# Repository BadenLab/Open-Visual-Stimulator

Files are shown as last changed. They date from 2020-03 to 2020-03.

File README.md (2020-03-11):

<p align="right">
<h1 align="center">Open Visual Stimulator</h1></p>
<h3 align="center">An open source arbitrary-spectrum spatial visual stimulator for vision research.</h4>
<p align="center"><h6 align="right">by K. Franke, A.M. Chagas, Z. Zhao, M.J.Y. Zimmermann, Y. Qiu, K. Szatko, T. Baden, T. Euler</h6></p>

<br>

### This project is a part of a larger work that can be found on the [Euler lab GitHub](https://github.com/eulerlab/open-visual-stimulator)

This project is licensed under the [MIT License](https://github.com/BadenLab/open-visual-stimulator/blob/master/LICENSE)<br>

<h4 align="justify">This repository holds the resources for a flexible, spatial visual stimulator with up to 6 chromatic channels. It combines commercial digital light processing (DLP) devices with open hard- and software components that can be easily adapted to the experimentalist’s specific needs. With this we intend to start a community effort of sharing and further developing a common stimulator design.</h4></p>

Please find more details on the stimulator in the following publication:

_Franke K*, Maia Chagas A*, Zhao Z, Zimmermann MJY, Bartel P, Qiu Y, Szatko K, Baden T, Euler T# (2019). An arbitrary-spectrum spatial visual stimulator for vision research. eLife 2019;8:e48779, [10.7554/eLife.48779](https://elifesciences.org/articles/48779)._

For the newest changes and additions, see [release notes](https://github.com/eulerlab/open-visual-stimulator/blob/master/release_notes.md)

### Pictures

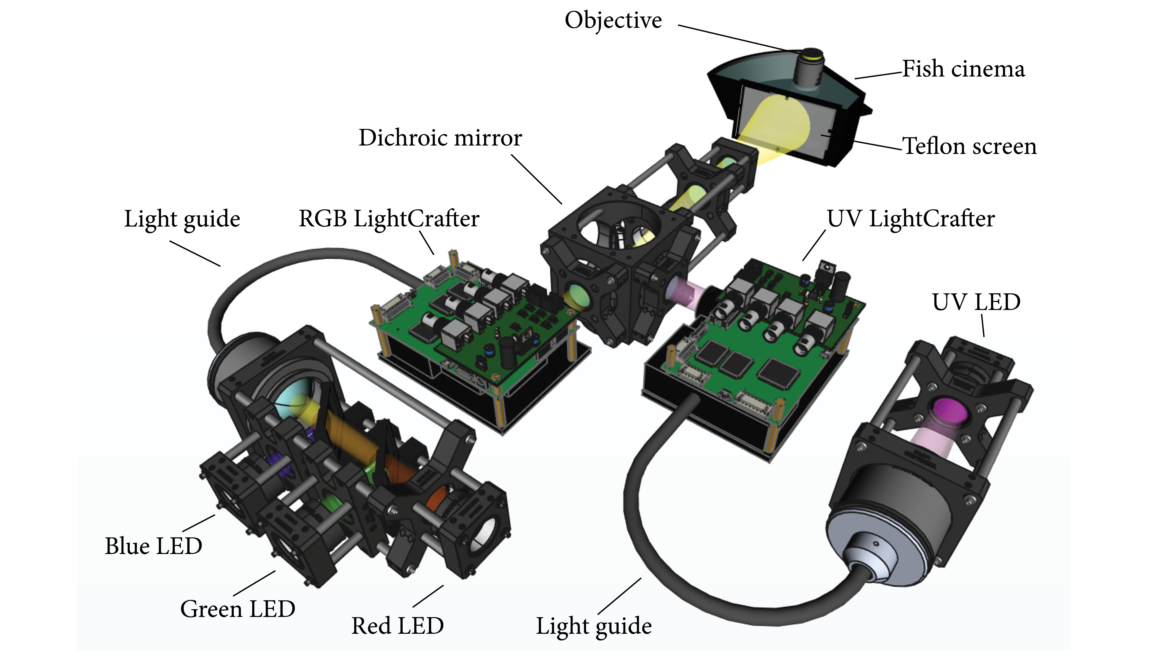
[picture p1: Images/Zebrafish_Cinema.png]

_Rendering of the 4-channel R-G-B-UV zebrafish stimulator._

### Ordering of PCB boards

If you are interested in ordering boards and components, please find more information in the boards folder [readme](https://github.com/badenlab/open-visual-stimulator/blob/master/PCB/readme.md) file.

## Repository structure

```
├───3D Designs                                OpenSCAD and STL files for 3D printed parts
|   |
│   ├───Fish_cinema                           - Fish tank used in the fish setup
│   ├───SSR_board                             - Designs for plate and cover of the SSR board
│   └───optical_components                    - optomechanical parts for LED assemblies
|           ├───fish_stimulator
|           └───lcr_addons
|
├───Images                                    Pictures
|
├───PCB                                       LED driver/blanking boards
│   ├───lcr_add-on                            - KiCad files for board that combines LCr and
|   |   |                                       blanking signals
|   |   ├───connector_coaxial.pretty          - BNC connector description (KiCad)
|   |   └───gerber                            - Gerber files for circuit board
│   ├───mosfet_circuit                        - KiCad files for board that switches switch LEDs
|   |   ├───connector_coaxial.pretty          - BNC connector description (KiCad)
|   |   └───gerber                            - Gerber files for circuit board
|   ├───mosfet_circuit_plus_voltage_regulator - KiCad files for board that combines voltage
|   |   |                                       regulator and LED switching
|   |   ├───connector_coaxial.pretty          - BNC connector description (KiCad)
|   |   └───gerbers                           - Gerber files for circuit board
|   ├───ssr_board                             - KiCad files for solid state relay board
|   |   └───gerbers                           - Gerber files for circuit board
|   └───arduino_code_for_testing_circuits     - Arduino code to emulate blanking and LCr signals
|       └───lcr_emulator
|
└───Stimulator Calibration                    Calibration of tetrachromatic zebrafish stimulator
    ├───data                                  - recorded calibration data (custom LEDs)
    ├───datasheets                            - spectrometer & powermeter data sheet.
    ├───light-sources                         - LED spectra measured behind the teflon screen
    ├───opsins                                - zebrafish opsin sensitivity curves
    └───scripts                               - Python scripts used in iPython notebooks
```

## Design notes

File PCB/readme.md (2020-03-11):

## LED driver/blanking boards

LED blanking circuits were inspired by earlier devices designed and built by R. Berndt (HIH Tübingen).

`lcr_add-on` - KiCad and Gerber files for the "logic board". This board combines the signals from the LCr with an external "blanking signal" to independently control up to three 3 LEDs per lightcrafter device. This board has a jumper option to disable the blanking signal altogether, which may be useful when e.g. using LCrs in MEA setups.

`mosfet_circuit` - KiCad and Gerber files for "LED driver board". This board uses the 5V logic signal from Lcr_addon ("logic board") to turn LEDs on and off. Users need to connect this board to an appropriate power suply (i.e. a power supply the is outputing the LED forward voltage).

`mosfet_circuit_plus_voltage_regulator` - KiCad and Gerber files for "LED driver board". This board uses the 5V logic signal from Lcr_addon ("logic board") to turn LEDs on and off. This board has a stepdown voltage regulator built-in. It is capable of 20V and 1.5A max output with the components present in its "1-click-bom.csv" file. (see "Components to populate the boards" for more details).

`ssr_board` - This board controls the LED power lines from the Lightcrafter by opening and closing them using solid state relays. The relays are controlled by a 5V signal (in this case the inverted blanking signal).

### General information about the printed circuit boards:

- For details on the design and function of the boards, see [preprint](https://www.biorxiv.org/content/10.1101/649566v1)).

- The boards were designed using [KiCad 5](http://www.kicad-pcb.org/) and can be ordered using the `Gerber.zip` file located in each board's `gerber` subfolder.

- Several "board on demand" companies are available, and the process of ordering is pretty much the same. A more detailed tutorial on how to do so can be found [here](https://www.youtube.com/watch?v=ENmDnoKs2hM) (for simply using the already available compressed files, go to minute 7 of the video).

- Companies providing "board on demand" service include:

   - [JLCPCB](https://jlcpcb.com/)
   - [PCBWAY](https://www.pcbway.com)
   - [OSH PARK](https://oshpark.com/)
   - [AISLER](https://aisler.net/)

### Components to populate the boards:

Components are listed on each board folder on a "comma separated value" file named `1-click-bom.csv`. Listed in the file are the quantity, identification and supplier of each component. They can also be ordered using [KitSpace](kitspace.org):

 - [LCr_addon on kitspace](https://kitspace.org/boards/github.com/eulerlab/open-visual-stimulator/boards/lcr_add-on/)
 - [mosfet circuit on kitspace](https://kitspace.org/boards/github.com/eulerlab/open-visual-stimulator/boards/mosfet_circuit/)

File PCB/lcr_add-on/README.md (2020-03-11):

# Open Visual Stimulator - LCR add-on PCB

A board for integrating signals from a lightcrafter to a 2P microscope ("logic board"), part of the Open source visual stimulator project.

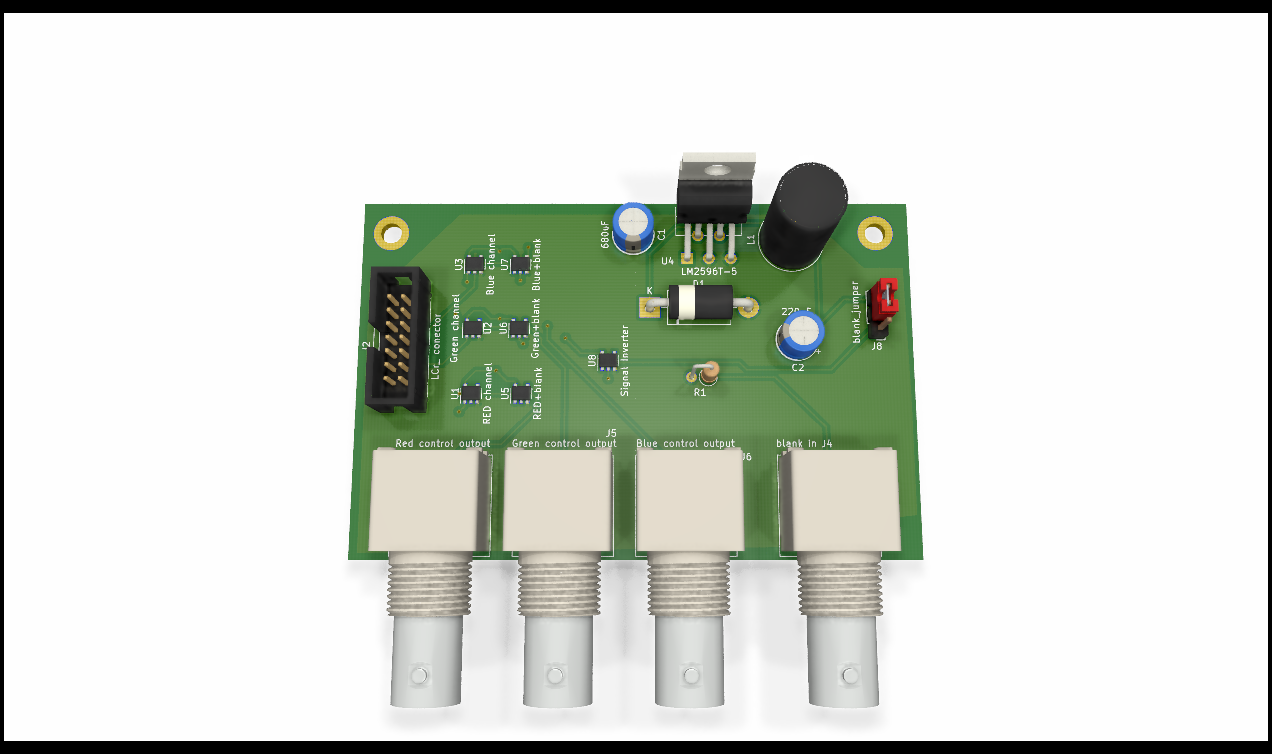
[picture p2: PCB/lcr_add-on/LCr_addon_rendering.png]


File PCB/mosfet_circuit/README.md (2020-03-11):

# Open Visual Stimulator - MOSFET Circuit PCB

A board ("LED driver board") for fast switching LEDs on/off, part of the Open Source visual stimulator project.

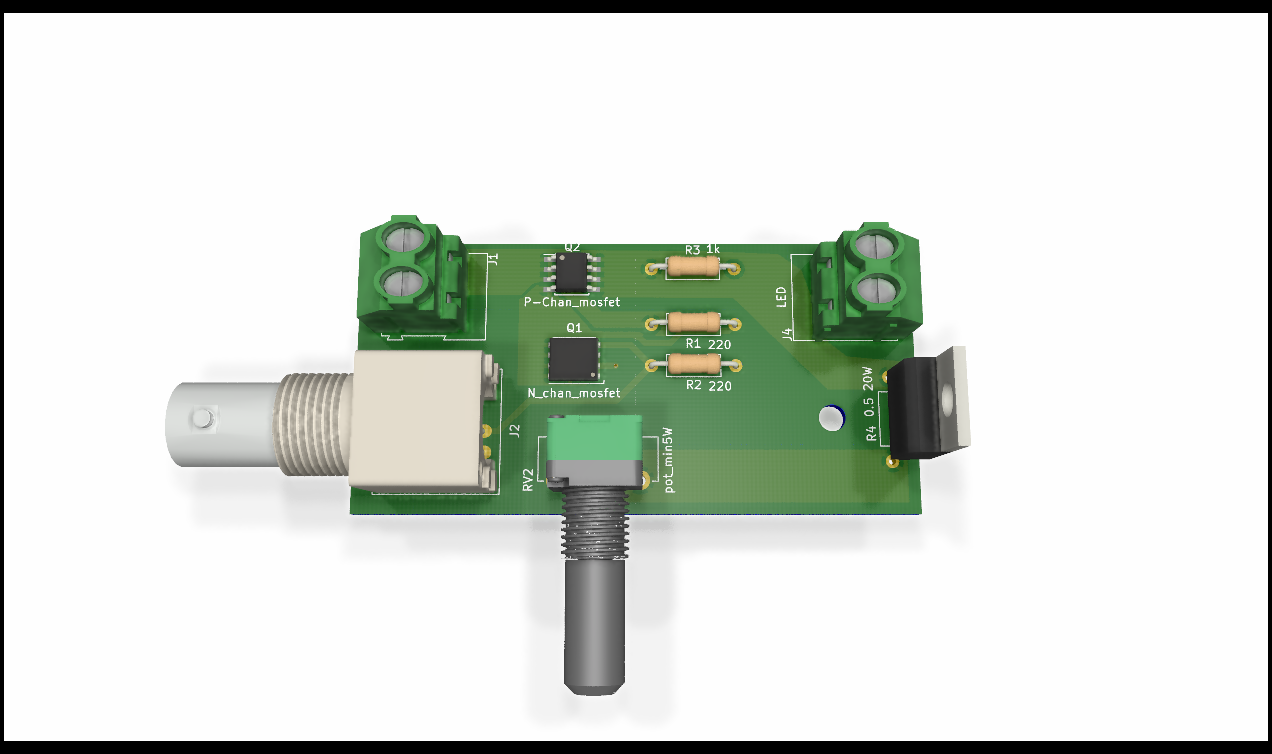
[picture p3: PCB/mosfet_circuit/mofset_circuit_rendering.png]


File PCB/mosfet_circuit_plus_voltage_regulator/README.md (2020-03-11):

# Open Visual Stimulator - mosfet circuit plus voltage regulator

A board that contains a voltage regulator and a fast switching (tens of microsseconds) circuit for turning LEDs on and off

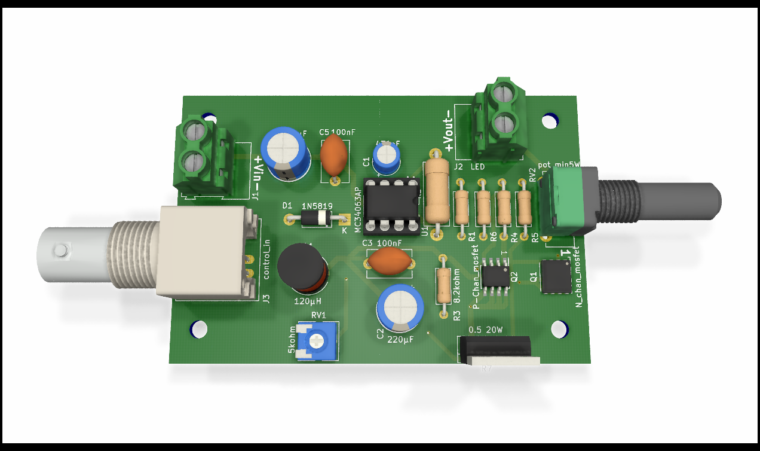
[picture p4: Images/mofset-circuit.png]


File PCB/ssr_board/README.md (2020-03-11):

# Open Visual Stimulator - Solid State relay board

This board controls the LED power lines from the Lightcrafter by opening and closing them using solid state relays. The relays are controlled by a 5V signal (in this case the inverted blanking signal).

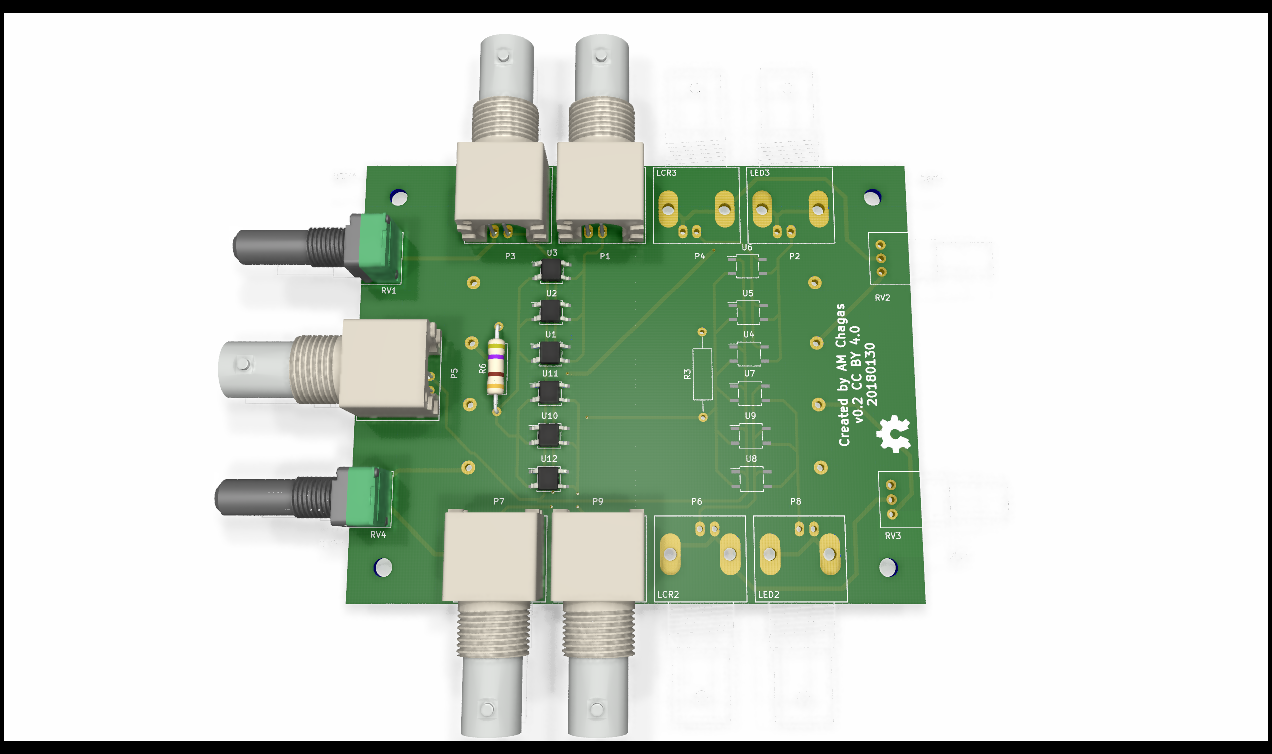
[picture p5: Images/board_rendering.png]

rendering for two out of four possible channels.

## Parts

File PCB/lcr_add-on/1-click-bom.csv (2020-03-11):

References | Qty | Description | Manufacturer | MPN | Manufacturer_1 | MPN_2 | Manufacturer_3 | MPN_4 | Manufacturer_5 | MPN_6 | Manufacturer_7 | MPN_8 | Digikey | Mouser | RS | Newark | Farnell
U4; | 1 | LM2596 5v | ITO-220 | Texas Instruments | Texas Instruments | LM2596T-5.0/NOPB |  |  |  |  |  |  | LM2596T-5.0/NOPB-ND | 926LM2596T5.0/NOPB | 5333743 | 97K3256 | 1150103
L1; | 1 | INDUCTOR 33µH Neosid MA-Bs75 | Bourns | RLB0914-330KL |  |  |  |  |  |  |  |  | RLB0914-330KL-ND | 652RLB0914330KL | 8118853 | 61J7916 | 2309242
D1; | 1 | Diode Schottky 5A DO-201AD | Vishay | 1N5822-E3/73 | Zetex | SB5100-T |  |  |  |  |  |  | 1N5822-E3/73GICT-ND | 6251N5822E3/73 | 751-4843 | 17T8202 | 1336553
C2; | 1 | CAP ALUM 220UF 20% 25V RADIAL | Panasonic | EEU-FM1E221 | Panasonic | ECA-1CM221B | Panasonic | ECE-A0GKS221 | Panasonic | EEU-EB1A221S |  |  | P12383-ND | 667ECA1CM221B | 7472036 | 70K9673 | 9451099
C1; | 1 | 680µF Capacitor | Rubycon | 16ZL680MEFC10X16 | Panasonic | EEU-FC1A681 |  |  |  |  |  |  | 1189-3978-ND | 667EEUFC1A681 | 7037258 | 31M6417 | 1144691
R1; | 1 | Resistor 1k 250mW through-hole | Multicomp | MF12 1K | Yageo | MFR-25FBF52-1K | RS Pro | 7077666 |  |  |  |  | 1.00KXBK-ND | 603MFR25FBF521K | 7077666 | 38K5400 | 9342400
J2; | 1 | Lcr connector | JST | B14B-PHDSS (LF)(SN) |  |  |  |  |  |  |  |  | 455-1764-ND |  | 918-2738
J4;J5;J6;J7; | 4 | BNC connector | TE | 1-1337542-0 |  |  |  |  |  |  |  |  | A97552-ND |  | 512-1203
J8; | 1 | jumper connector | SamTec | SSW-103-01-G-S |  |  |  |  |  |  |  |  | SAM1209-03-ND |  | 765-5610
U1;U2;U3:U5;U6:U7 | 6 | AND gate | NXP | '74AHC1G08GW | 125' |  |  |  |  |  |  |  |  | 1727-3148-1-ND | 144-5258 | 510-087
U8; | 1 | Signal inverter (NOT gate) | Toshiba | TC7SH14F(F) | Texas Instruments | 74AHC1G14SE-7 |  |  |  |  |  |  | 74AHC1G14SE-7DICT-ND |  | 540-6885
Lcr 1 | 2 | Female plug 2X14 (1 to Lcr one to Board) | JST | PHDR-14VS |  |  |  |  |  |  |  |  | 455-1172-ND |  | 917-4692 | 917-4692
Cable | 14 | JUMPER SPHD-001T-P0.5 X2 10 | JST | APAPA22K254 |  |  |  |  |  |  |  |  | 455-3357-ND

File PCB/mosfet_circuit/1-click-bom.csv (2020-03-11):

References | Qty | Description | Manufacturer | MPN | Manufacturer_1 | MPN_2 | Manufacturer_3 | MPN_4 | Manufacturer_5 | MPN_6 | Manufacturer_7 | MPN_8 | Digikey | Mouser | RS | Newark | Farnell
Q2 | 1 | P-Channel MOSFET | Fairchild | FDS6575 |  |  |  |  |  |  |  |  | FDS6575CT-ND |  | 671-0570
Q1 | 1 | N-Channel mosfet | Vishay | SI4840BDY-T1-GE3 |  |  |  |  |  |  |  |  | SI4840BDY-T1-E3CT-ND |  | 710-4736
'R1;R2''' | 2 | Resistor 220 ohm 250mW through-hole | Yageo | MFR-25FBF52-220R | TE Connectivity | CBT25J220R | TE Connectivity | CFR16J220R | Ohmite | OD221JE | Stackpole Electronics | CF14JT220R | CF14JT220RCT-ND | 279CBT25J220R | 8066376 | 21R0186 | 1265068
R3 | 1 | Resistor 1k 250mW through-hole | Multicomp | MF12 1K | Yageo | MFR-25FBF52-1K | RS Pro | 7077666 |  |  |  |  | 1.00KXBK-ND | 603MFR25FBF521K | 7077666 | 38K5400 | 9342400
R4; | 1 | Resistor 20W TO-220 | Bourns | PWR220T-20-R500F |  |  |  |  |  |  |  |  | PWR220T-20-R500F-ND | 652PWR220T20R500F | 7962508 | 55R1098 | 2328267
J1;J4 | 2 | Terminal block 5mm | RS Pro | 494-8906 | TE Connectivity | 282837-2 |  |  |  |  |  |  | A113320-ND |  | 494-8906
RV2 | 1 | Potentiometer 25Ohms 5W | CTS | 026TB32R250B1A1 |  |  |  |  |  |  |  |  | CT2152-ND |  | 179-0668
J2 | 1 | BNC connector | TE | 1-1337542-0 |  |  |  |  |  |  |  |  | A97552-ND |  | 512-1203

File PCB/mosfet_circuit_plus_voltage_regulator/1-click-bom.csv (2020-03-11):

References | Qty | Description | Manufacturer | MPN | Manufacturer_1 | MPN_2 | Manufacturer_3 | MPN_4 | Manufacturer_5 | MPN_6 | Manufacturer_7 | MPN_8 | Digikey | Mouser | RS | Newark | Farnell
Q2 | 1 | P-Channel MOSFET | Fairchild | FDS6575 |  |  |  |  |  |  |  |  | FDS6575CT-ND |  | 671-0570
Q1 | 1 | N-Channel mosfet | Vishay | SI4840BDY-T1-GE3 |  |  |  |  |  |  |  |  | SI4840BDY-T1-E3CT-ND |  | 710-4736
R1 | 1 | 1.5kohm | TE Connectivity | LR1F1K5 |  |  |  |  |  |  |  |  | A105952CT-ND |  | 148-540
R2 | 1 | 0.22ohm | Vishay | RWM0410R220JR15E1 |  |  |  |  |  |  |  |  | RWMA-.22CT-ND |  | 485-1414
R3 | 1 | 8.2kohm | TE Connectivity | LR1F8K2 | Vishay | MRS25000C8201FCT00 |  |  |  |  |  |  | BC4264CT-ND |  | 148-714
R4;R5 | 2 | Resistor 220 ohm 250mW through-hole | Yageo | MFR-25FBF52-220R | TE Connectivity | CBT25J220R | TE Connectivity | CFR16J220R | Ohmite | OD221JE | Stackpole Electronics | CF14JT220R | CF14JT220RCT-ND | 279CBT25J220R | 8066376 | 21R0186 | 1265068
R6 | 1 | Resistor 1k 250mW through-hole | Multicomp | MF12 1K | Yageo | MFR-25FBF52-1K | RS Pro | 7077666 |  |  |  |  | 1.00KXBK-ND | 603MFR25FBF521K | 7077666 | 38K5400 | 9342400
R7 | 1 | Resistor 20W TO-220 | Bourns | PWR220T-20-R500F |  |  |  |  |  |  |  |  | PWR220T-20-R500F-ND | 652PWR220T20R500F | 7962508 | 55R1098 | 2328267
J1;J2 | 2 | Terminal block 5mm | RS Pro | 494-8956 | TE Connectivity | 282836-2 | TE Connectivity | 282837-2 |  |  |  |  | A113320-ND |  | 494-8956
J3 | 1 | BNC connector | TE | 1-1337542-0 |  |  |  |  |  |  |  |  | A97552-ND |  | 512-1203
RV1 | 1 | 5kohm | Bourns | 3362P-1-502LF |  |  |  |  |  |  |  |  | 3362P-502LF-ND |  | 522-0978
RV2 | 1 | Potentiometer 25Ohms 5W | CTS | 026TB32R250B1A1 |  |  |  |  |  |  |  |  | CT2152-ND |  | 179-0668
D1 | 1 | 1N5819 diode | ON | 1N5819G |  |  |  |  |  |  |  |  | 1N5819GOS-ND |  | 774-3347
C1 |  | 470pF capacitor | Vishay | 562R10TST47 |  |  |  |  |  |  |  |  | 562R10TST47-ND |  | 831-3023
C2;C4 |  | 220µF capacitor (line filter) | Vishay | MAL214650221E3 |  |  |  |  |  |  |  |  | 4485PHBK-ND |  | 684-1725
C3;C5 |  | 100nF capacitor (line filter) | Wima | MKS2D031001A00KI00 | TDK | FG26C0G1H104JNT06 |  |  |  |  |  |  | 445-173396-1-ND |  | 108-2700
L1 |  | 120µH inductor | Panasonic | ELC11D121F | Bourns | RL622-121K-RC |  |  |  |  |  |  | M9994-ND |  | 675-5400
U1 |  | MC34063AP step up/down regulator | texas instruments | MC34063AP |  |  |  |  |  |  |  |  | 296-17766-5-ND |  | 661-8430
U1-1 |  | DIP-8 socket | Preci-dip | 110-87-308-41-001101 | Assmann | A 08-LC-TT |  |  |  |  |  |  | AE9986-ND |  | 674-2435

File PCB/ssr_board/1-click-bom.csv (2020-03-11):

References | Qty | Description | Manufacturer | MPN | Manufacturer_1 | MPN_2 | Manufacturer_3 | MPN_4 | Manufacturer_5 | MPN_6 | Manufacturer_7 | MPN_8 | Digikey | Mouser | RS | Newark | Farnell
P1-9 | 9 | BNC connector | TE | 1-1337542-0 |  |  |  |  |  |  |  |  |  |  | 512-1203
R3;R6 | 2 | Resistor 1k 250mW through-hole | Multicomp | MF12 1K | Yageo | MFR-25FBF52-1K | RS Pro | 7077666 |  |  |  |  | 1.00KXBK-ND | 603MFR25FBF521K | 7077666 | 38K5400 | 9342400
RV1-4 | 4 | Potentiometer 25Ohms 5W | CTS | 026TB32R250B1A1 |  |  |  |  |  |  |  |  |  |  | 179-0668
U1-12 | 12 | Optocoupler 250mA max current | Panasonic | AQY221R2S |  |  |  |  |  |  |  |  |  |  | 699-6610
R1;R2;R4;R5 | 4 | 2 Ohm 5W resistor | Vishay | RS0052R000FE12 |  |  |  |  |  |  |  |  |  |  | 850-6613

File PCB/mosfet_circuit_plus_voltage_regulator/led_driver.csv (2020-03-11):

Source: | /home/andre/Documents/repositories/amchagas/open-visual-stimulator/boards/mosfet_circuit_plus_voltage_regulator/led_driver.sch
Date: | Fri 19 Jul 2019 14:24:53 BST
Tool: | Eeschema 5.0.2-bee76a0~70~ubuntu18.04.1
Component Count: | 26
Ref | Value | Footprint | Datasheet | Manufacturer | Vendor
C1 | 470pF | Capacitor_THT:CP_Radial_D5.0mm_P2.50mm | ~
C2 | 220µF | Capacitor_THT:CP_Radial_D8.0mm_P5.00mm | ~
C3 | 100nF | Capacitor_THT:C_Disc_D8.0mm_W5.0mm_P7.50mm | ~
C4 | 220µF | Capacitor_THT:CP_Radial_D8.0mm_P5.00mm | ~
C5 | 100nF | Capacitor_THT:C_Disc_D8.0mm_W5.0mm_P7.50mm | ~
D1 | 1N5819 | Diode_THT:D_DO-41_SOD81_P10.16mm_Horizontal | http://www.vishay.com/docs/88525/1n5817.pdf
H1 | MountingHole | MountingHole:MountingHole_3.2mm_M3 | ~
H2 | MountingHole | MountingHole:MountingHole_3.2mm_M3 | ~
H3 | MountingHole | MountingHole:MountingHole_3.2mm_M3 | ~
H4 | MountingHole | MountingHole:MountingHole_3.2mm_M3 | ~
J1 | Vin | TerminalBlock:TerminalBlock_Altech_AK300-2_P5.00mm | ~
J2 | LED | TerminalBlock:TerminalBlock_Altech_AK300-2_P5.00mm | ~
J3 | control_in | Connector_Coaxial_extra:BNC_Amphenol_B6252HB-NPP3G-50_Horizontal | ~
L1 | 120µH | Inductor_THT:L_Radial_D7.5mm_P5.00mm_Fastron_07P | ~
Q1 | N_chan_mosfet | Package_TO_SOT_SMD:TDSON-8-1 | http://www.ti.com/lit/gpn/csd17577q5a
Q2 | P-Chan_mosfet | Package_SO:SOIC-8_3.9x4.9mm_P1.27mm | http://www.infineon.com/dgdl/irf7404.pdf?fileId=5546d462533600a4015355fa2b5b1b9e
R1 | 1.5kohm | Resistor_THT:R_Axial_DIN0207_L6.3mm_D2.5mm_P10.16mm_Horizontal | ~
R2 | 0.22ohm | Resistor_THT:R_Axial_DIN0414_L11.9mm_D4.5mm_P15.24mm_Horizontal | ~
R3 | 8.2kohm | Resistor_THT:R_Axial_DIN0207_L6.3mm_D2.5mm_P10.16mm_Horizontal | ~
R4 | 220 | Resistor_THT:R_Axial_DIN0207_L6.3mm_D2.5mm_P10.16mm_Horizontal | ~
R5 | 220 | Resistor_THT:R_Axial_DIN0207_L6.3mm_D2.5mm_P10.16mm_Horizontal | ~
R6 | 1k | Resistor_THT:R_Axial_DIN0207_L6.3mm_D2.5mm_P10.16mm_Horizontal | ~
R7 | 0.5 20W | Package_TO_SOT_THT:TO-220-2_Vertical | ~
RV1 | 5kohm | Potentiometer_THT:Potentiometer_Vishay_T73YP_Vertical | ~
RV2 | pot_min5W | Potentiometer_THT:Potentiometer_ACP_CA14-H5_Horizontal | ~
U1 | MC34063AP | Package_DIP:DIP-8_W7.62mm | http://www.onsemi.com/pub_link/Collateral/MC34063A-D.PDF

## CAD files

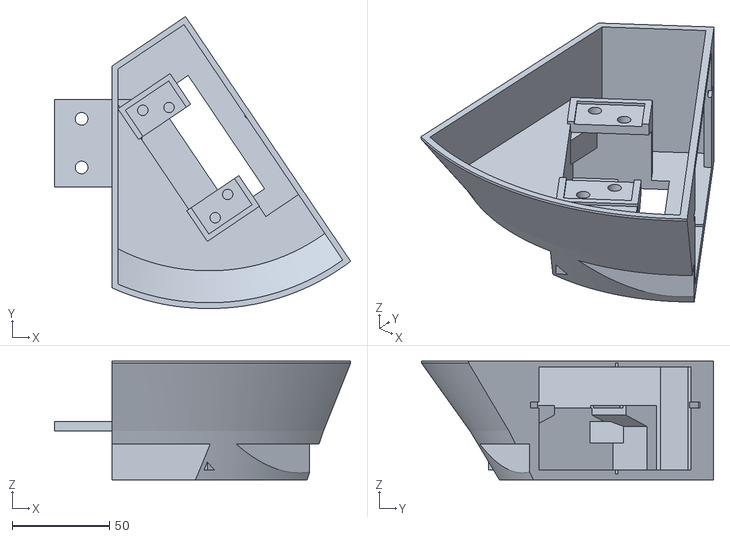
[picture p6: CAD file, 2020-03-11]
3D Designs/Fish_cinema/Fish Cinema v10.0_40X_Objective.stl
152.3 x 150.1 x 61.0

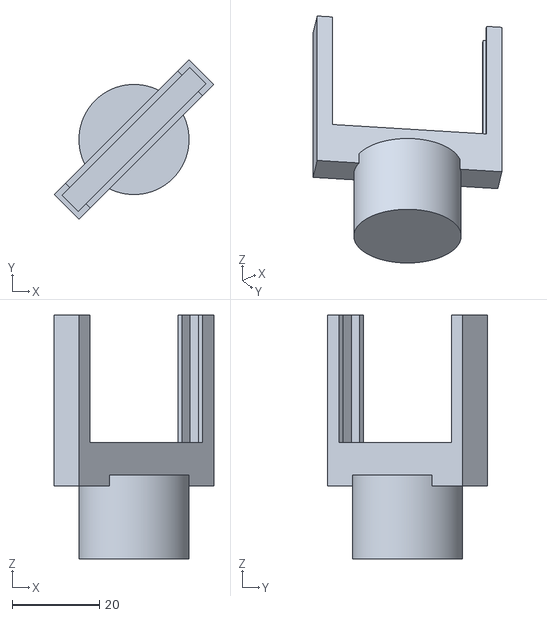
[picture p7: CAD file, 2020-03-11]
3D Designs/optical_components/fish_stimulator/dichroic_holder.stl
36.6 x 36.6 x 55.9

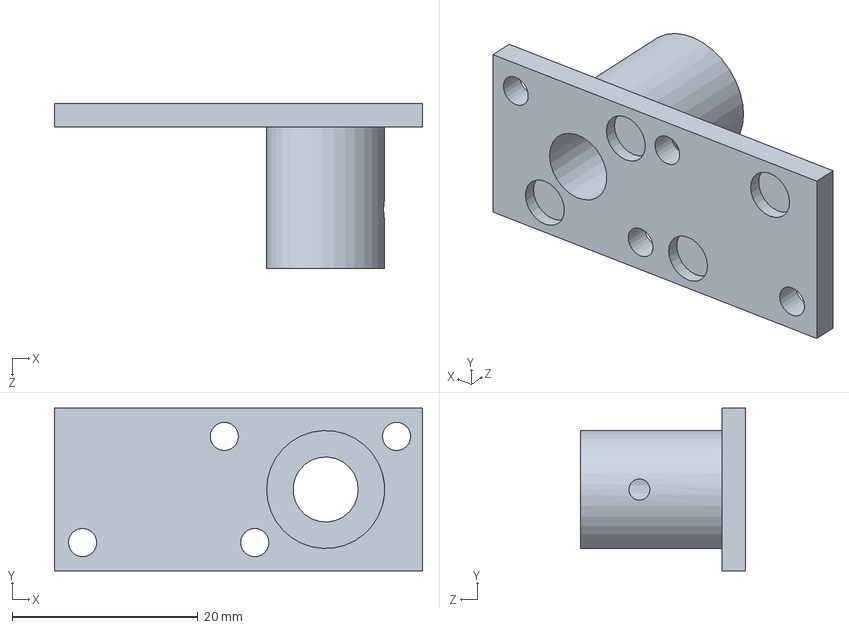
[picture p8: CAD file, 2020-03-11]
3D Designs/optical_components/lcr_addons/fibre_coupler/light guide holder.SLDPRT
39.6 x 17.5 x 17.8 mm

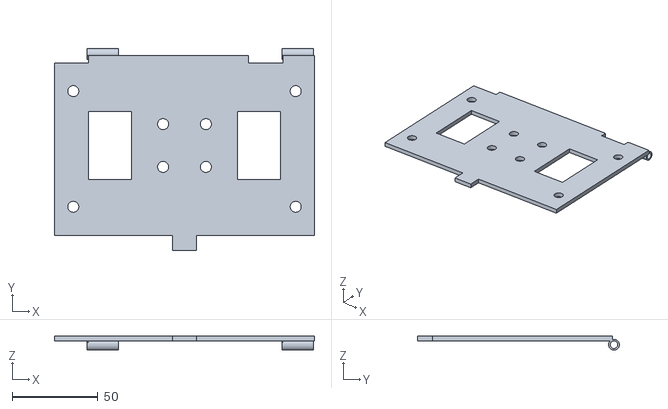
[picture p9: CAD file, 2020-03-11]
3D Designs/optical_components/lcr_addons/LCr_tilter/Lcr_tilter_plate2.stl
152.0 x 118.0 x 8.40

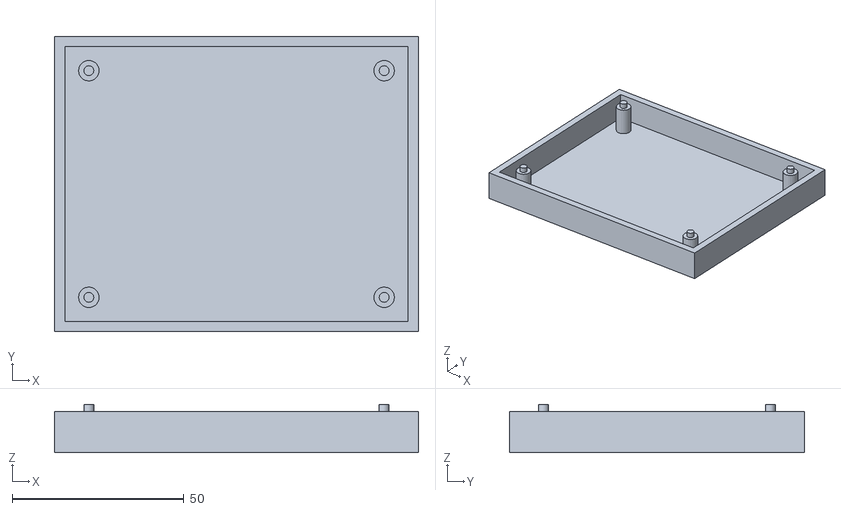
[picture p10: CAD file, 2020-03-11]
3D Designs/SSR_board/pcb_case_bottom.stl
106.0 x 86.0 x 14.0

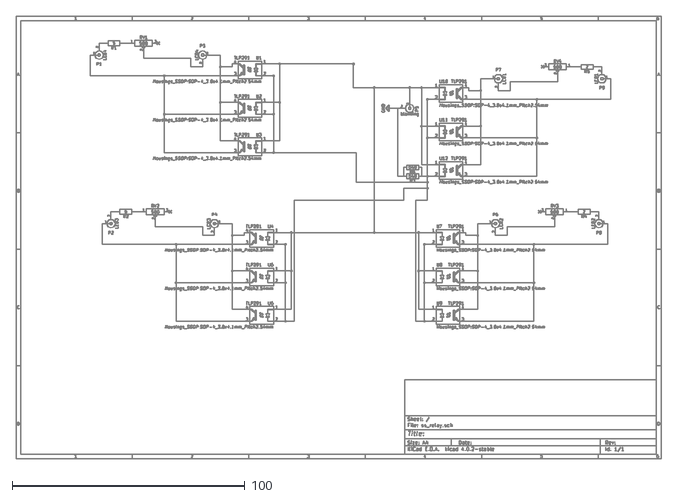
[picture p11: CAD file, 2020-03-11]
PCB/ssr_board/ss_relay.dxf
277.0 x 190.0

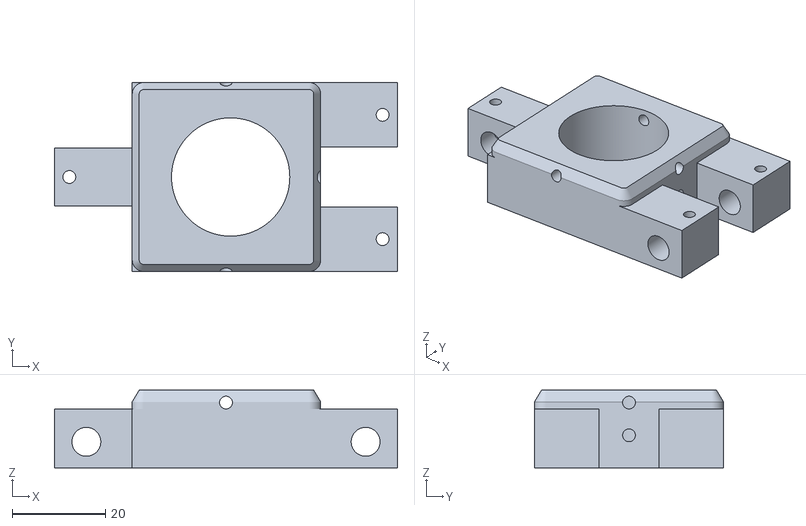
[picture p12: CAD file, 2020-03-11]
3D Designs/optical_components/fish_stimulator/LCP30 - modified.stl
73.7 x 40.6 x 16.7

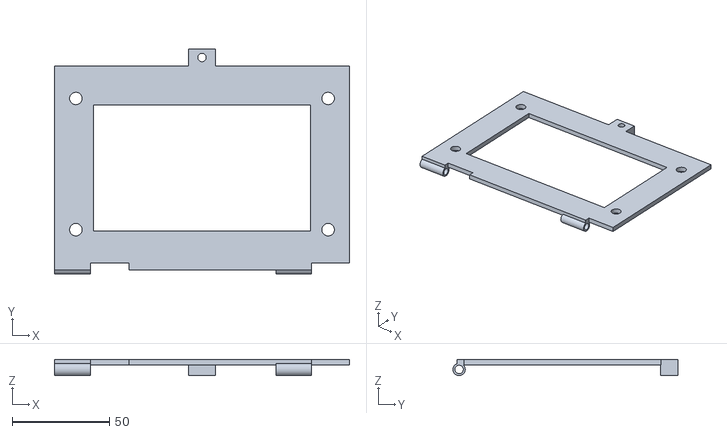
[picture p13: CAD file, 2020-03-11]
3D Designs/optical_components/lcr_addons/LCr_tilter/Lcr_tilter_plate1.stl
152.0 x 116.0 x 8.40

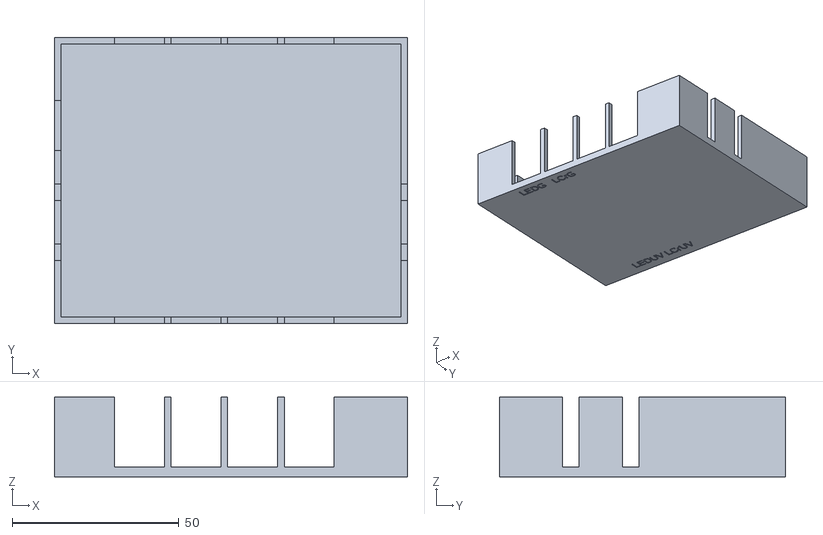
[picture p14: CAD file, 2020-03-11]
3D Designs/SSR_board/pcb_case_top.stl
106.0 x 86.0 x 24.0

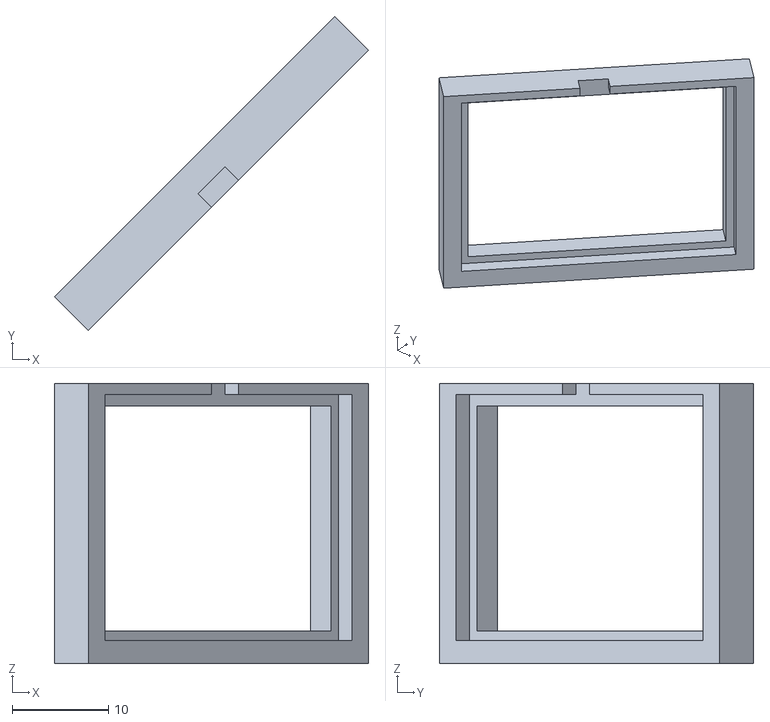
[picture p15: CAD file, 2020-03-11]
3D Designs/optical_components/fish_stimulator/dichroic_frame.stl
32.7 x 32.7 x 29.1

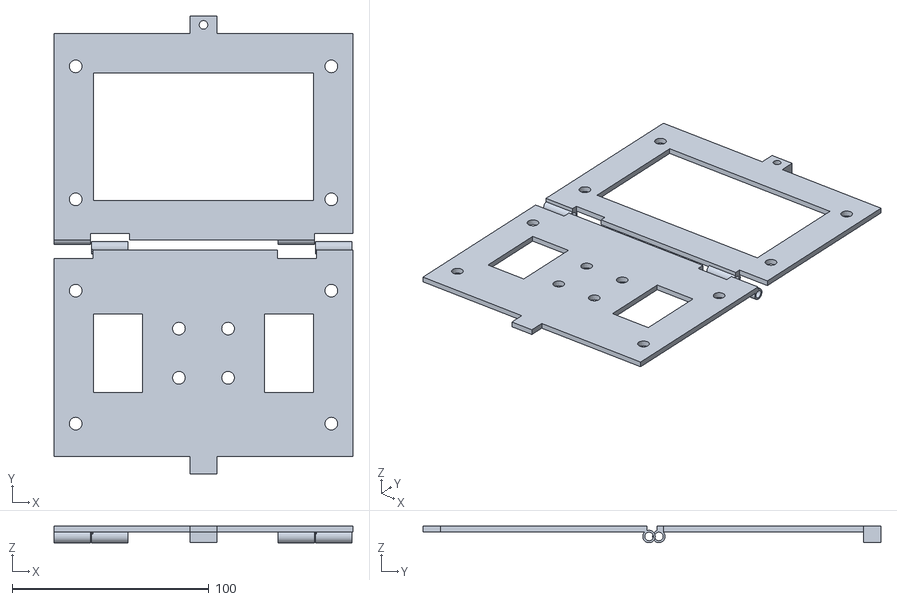
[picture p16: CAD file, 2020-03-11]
3D Designs/optical_components/lcr_addons/LCr_tilter/Lcr_tilter.stl
152.0 x 232.7 x 8.40

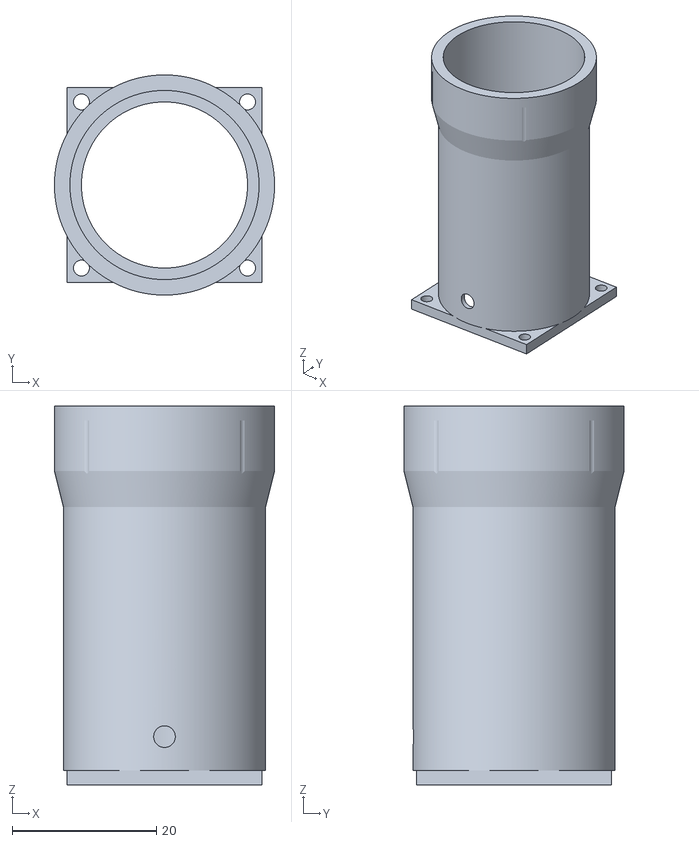
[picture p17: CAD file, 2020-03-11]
3D Designs/optical_components/fish_stimulator/DMD_lens_adapter.stl
30.5 x 30.5 x 52.5

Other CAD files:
3D Designs/optical_components/fish_stimulator/DMD_lens_adapter.scad
3D Designs/optical_components/fish_stimulator/Optical Components.scad
3D Designs/Fish_cinema/Fish Cinema v10.0_40X_Objective.scad
3D Designs/SSR_board/pcb_case_bottom.scad
3D Designs/SSR_board/pcb_case_top.scad
3D Designs/optical_components/lcr_addons/LCr_tilter/Lcr_tilter.scad
3D Designs/optical_components/lcr_addons/fibre_coupler/light guide holder.IGS
3D Designs/optical_components/lcr_addons/fibre_coupler/light guide holder.STL
3D Designs/optical_components/lcr_addons/fibre_coupler/light guide holder.x_t

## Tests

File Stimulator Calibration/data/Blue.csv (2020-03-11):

Optical Power Monitor
1.1.2315.102
Delimiter Used:
Start of Measurement | 7/18/2019 18:23:52
Sample Interval | 1 s
 | PM100D 18112641
Type | PM100D
Serialnumber | P0009872
Sensor | S130VC
SensorSerialnumber | 18112641
Wavelength / Responsivity | 411 nm
 |  |  | PM100D 18112641
Samples | Date (MM/dd/yyyy) | Time of day (hh:mm:ss) | Power (W)
0 | 7/18/2019 | 18:23:52 | -1.467E-09
1 | 7/18/2019 | 18:23:54 | -1.4671E-09
2 | 7/18/2019 | 18:23:55 | -1.4672E-09
3 | 7/18/2019 | 18:23:56 | -1.4675E-09
4 | 7/18/2019 | 18:23:57 | -1.4672E-09
5 | 7/18/2019 | 18:23:58 | -1.4672E-09
6 | 7/18/2019 | 18:23:59 | -1.4674E-09
7 | 7/18/2019 | 18:24:00 | -1.4668E-09
8 | 7/18/2019 | 18:24:01 | -1.4674E-09
9 | 7/18/2019 | 18:24:02 | -1.4675E-09
10 | 7/18/2019 | 18:24:03 | -1.4678E-09
11 | 7/18/2019 | 18:24:04 | -1.467E-09
12 | 7/18/2019 | 18:24:05 | -1.4663E-09
13 | 7/18/2019 | 18:24:06 | -1.4634E-09
14 | 7/18/2019 | 18:24:07 | -1.4596E-09
15 | 7/18/2019 | 18:24:08 | -1.4522E-09
16 | 7/18/2019 | 18:24:09 | -1.4453E-09
17 | 7/18/2019 | 18:24:10 | -1.4357E-09
18 | 7/18/2019 | 18:24:11 | -1.4236E-09
19 | 7/18/2019 | 18:24:12 | -1.4116E-09
20 | 7/18/2019 | 18:24:13 | -1.3955E-09
21 | 7/18/2019 | 18:24:14 | -1.3764E-09
22 | 7/18/2019 | 18:24:15 | -1.3533E-09
23 | 7/18/2019 | 18:24:16 | -1.3295E-09
24 | 7/18/2019 | 18:24:17 | -1.3E-09
25 | 7/18/2019 | 18:24:18 | -1.2729E-09
26 | 7/18/2019 | 18:24:19 | -1.24E-09
27 | 7/18/2019 | 18:24:20 | -1.2099E-09
28 | 7/18/2019 | 18:24:21 | -1.1768E-09
29 | 7/18/2019 | 18:24:22 | -1.1484E-09
30 | 7/18/2019 | 18:24:23 | -1.1118E-09
31 | 7/18/2019 | 18:24:24 | -1.0811E-09
32 | 7/18/2019 | 18:24:25 | -1.0454E-09
33 | 7/18/2019 | 18:24:26 | -1.0153E-09
34 | 7/18/2019 | 18:24:27 | -9.6522E-10
35 | 7/18/2019 | 18:24:28 | -9.5123E-10
36 | 7/18/2019 | 18:24:29 | -9.3208E-10
37 | 7/18/2019 | 18:24:30 | -8.866E-10
38 | 7/18/2019 | 18:24:31 | -8.5727E-10
39 | 7/18/2019 | 18:24:32 | -8.0304E-10
40 | 7/18/2019 | 18:24:33 | -7.7982E-10
41 | 7/18/2019 | 18:24:34 | -7.3254E-10
42 | 7/18/2019 | 18:24:35 | -7.0772E-10
43 | 7/18/2019 | 18:24:36 | -6.5643E-10
44 | 7/18/2019 | 18:24:37 | -6.186E-10
45 | 7/18/2019 | 18:24:38 | -5.7324E-10
46 | 7/18/2019 | 18:24:39 | -5.2809E-10
47 | 7/18/2019 | 18:24:40 | -4.9467E-10
48 | 7/18/2019 | 18:24:41 | -4.4673E-10
49 | 7/18/2019 | 18:24:42 | -3.8962E-10
50 | 7/18/2019 | 18:24:43 | -3.3287E-10
51 | 7/18/2019 | 18:24:44 | -2.8128E-10
52 | 7/18/2019 | 18:24:45 | -2.0966E-10
53 | 7/18/2019 | 18:24:46 | -1.808E-10
54 | 7/18/2019 | 18:24:47 | -1.0912E-10
55 | 7/18/2019 | 18:24:48 | -7.9016E-11
56 | 7/18/2019 | 18:24:49 | 7.7298E-12
57 | 7/18/2019 | 18:24:50 | 5.5435E-11
58 | 7/18/2019 | 18:24:51 | 1.6318E-10
59 | 7/18/2019 | 18:24:52 | 2.1366E-10
60 | 7/18/2019 | 18:24:53 | 2.9612E-10
61 | 7/18/2019 | 18:24:54 | 3.4192E-10
62 | 7/18/2019 | 18:24:55 | 4.3923E-10
63 | 7/18/2019 | 18:24:56 | 4.819E-10
64 | 7/18/2019 | 18:24:57 | 5.7767E-10
65 | 7/18/2019 | 18:24:58 | 6.557E-10
66 | 7/18/2019 | 18:24:59 | 7.0857E-10
67 | 7/18/2019 | 18:25:00 | 8.1741E-10
68 | 7/18/2019 | 18:25:01 | 8.9597E-10
69 | 7/18/2019 | 18:25:02 | 9.9586E-10
70 | 7/18/2019 | 18:25:03 | 1.0905E-09
71 | 7/18/2019 | 18:25:04 | 1.2002E-09
72 | 7/18/2019 | 18:25:05 | 1.3097E-09
73 | 7/18/2019 | 18:25:06 | 1.3985E-09
74 | 7/18/2019 | 18:25:07 | 1.4615E-09
75 | 7/18/2019 | 18:25:08 | 1.5589E-09
76 | 7/18/2019 | 18:25:09 | 1.669E-09
77 | 7/18/2019 | 18:25:10 | 1.7763E-09
78 | 7/18/2019 | 18:25:11 | 1.8649E-09
79 | 7/18/2019 | 18:25:12 | 1.9974E-09
80 | 7/18/2019 | 18:25:13 | 2.1072E-09
81 | 7/18/2019 | 18:25:14 | 2.2107E-09
82 | 7/18/2019 | 18:25:15 | 2.3242E-09
83 | 7/18/2019 | 18:25:16 | 2.4166E-09
84 | 7/18/2019 | 18:25:17 | 2.501E-09
85 | 7/18/2019 | 18:25:18 | 2.5758E-09
86 | 7/18/2019 | 18:25:19 | 2.721E-09
87 | 7/18/2019 | 18:25:20 | 2.8067E-09
88 | 7/18/2019 | 18:25:21 | 2.9013E-09
89 | 7/18/2019 | 18:25:22 | 3.0479E-09
90 | 7/18/2019 | 18:25:23 | 3.2034E-09
91 | 7/18/2019 | 18:25:24 | 3.3062E-09
92 | 7/18/2019 | 18:25:25 | 3.4365E-09
93 | 7/18/2019 | 18:25:26 | 3.5171E-09
94 | 7/18/2019 | 18:25:27 | 3.6244E-09
95 | 7/18/2019 | 18:25:28 | 3.7864E-09
96 | 7/18/2019 | 18:25:29 | 3.8858E-09
97 | 7/18/2019 | 18:25:30 | 4.0603E-09
98 | 7/18/2019 | 18:25:31 | 4.1982E-09
99 | 7/18/2019 | 18:25:32 | 4.4447E-09
100 | 7/18/2019 | 18:25:33 | 4.5665E-09
101 | 7/18/2019 | 18:25:34 | 4.8535E-09
102 | 7/18/2019 | 18:25:35 | 4.9242E-09
103 | 7/18/2019 | 18:25:36 | 5.1564E-09
104 | 7/18/2019 | 18:25:37 | 5.2384E-09
105 | 7/18/2019 | 18:25:38 | 5.6182E-09
106 | 7/18/2019 | 18:25:39 | 5.7218E-09
107 | 7/18/2019 | 18:25:40 | 5.9529E-09
108 | 7/18/2019 | 18:25:41 | 6.0964E-09
109 | 7/18/2019 | 18:25:42 | 6.4383E-09
110 | 7/18/2019 | 18:25:43 | 6.7087E-09
111 | 7/18/2019 | 18:25:44 | 6.9794E-09
112 | 7/18/2019 | 18:25:45 | 7.3282E-09
113 | 7/18/2019 | 18:25:46 | 7.5784E-09
114 | 7/18/2019 | 18:25:47 | 7.9323E-09
115 | 7/18/2019 | 18:25:48 | 8.0899E-09
116 | 7/18/2019 | 18:25:49 | 8.4584E-09
117 | 7/18/2019 | 18:25:50 | 8.5848E-09
118 | 7/18/2019 | 18:25:51 | 9.1317E-09
119 | 7/18/2019 | 18:25:52 | 9.3362E-09
120 | 7/18/2019 | 18:25:53 | 9.7365E-09
121 | 7/18/2019 | 18:25:54 | 9.8785E-09
122 | 7/18/2019 | 18:25:55 | 1.0265E-08
123 | 7/18/2019 | 18:25:56 | 1.0348E-08
124 | 7/18/2019 | 18:25:57 | 1.0479E-08
125 | 7/18/2019 | 18:25:58 | 1.0968E-08
126 | 7/18/2019 | 18:25:59 | 1.1069E-08
127 | 7/18/2019 | 18:26:00 | 1.1551E-08
128 | 7/18/2019 | 18:26:01 | 1.1761E-08
129 | 7/18/2019 | 18:26:02 | 1.2117E-08
130 | 7/18/2019 | 18:26:03 | 1.2389E-08
131 | 7/18/2019 | 18:26:04 | 1.2776E-08
132 | 7/18/2019 | 18:26:05 | 1.3071E-08
133 | 7/18/2019 | 18:26:06 | 1.3424E-08
134 | 7/18/2019 | 18:26:07 | 1.3712E-08
135 | 7/18/2019 | 18:26:08 | 1.4126E-08
136 | 7/18/2019 | 18:26:09 | 1.4228E-08
137 | 7/18/2019 | 18:26:10 | 1.4781E-08
138 | 7/18/2019 | 18:26:11 | 1.4989E-08
139 | 7/18/2019 | 18:26:12 | 1.5485E-08
140 | 7/18/2019 | 18:26:13 | 1.5857E-08
141 | 7/18/2019 | 18:26:14 | 1.6346E-08
142 | 7/18/2019 | 18:26:15 | 1.6828E-08
143 | 7/18/2019 | 18:26:16 | 1.7208E-08
144 | 7/18/2019 | 18:26:17 | 1.7797E-08
145 | 7/18/2019 | 18:26:18 | 1.8012E-08
146 | 7/18/2019 | 18:26:19 | 1.8614E-08
147 | 7/18/2019 | 18:26:20 | 1.8694E-08
148 | 7/18/2019 | 18:26:21 | 1.9388E-08
149 | 7/18/2019 | 18:26:22 | 1.9432E-08
150 | 7/18/2019 | 18:26:23 | 2.0132E-08
151 | 7/18/2019 | 18:26:24 | 2.0245E-08
152 | 7/18/2019 | 18:26:25 | 2.0872E-08
153 | 7/18/2019 | 18:26:26 | 2.1149E-08
154 | 7/18/2019 | 18:26:27 | 2.179E-08
155 | 7/18/2019 | 18:26:28 | 2.2102E-08
156 | 7/18/2019 | 18:26:29 | 2.2774E-08
157 | 7/18/2019 | 18:26:30 | 2.3053E-08
158 | 7/18/2019 | 18:26:31 | 2.374E-08
159 | 7/18/2019 | 18:26:32 | 2.4099E-08
160 | 7/18/2019 | 18:26:33 | 2.4557E-08
161 | 7/18/2019 | 18:26:34 | 2.5073E-08
162 | 7/18/2019 | 18:26:35 | 2.5566E-08
163 | 7/18/2019 | 18:26:36 | 2.6277E-08
164 | 7/18/2019 | 18:26:37 | 2.6689E-08
165 | 7/18/2019 | 18:26:38 | 2.7502E-08
166 | 7/18/2019 | 18:26:39 | 2.7674E-08
167 | 7/18/2019 | 18:26:40 | 2.8659E-08
168 | 7/18/2019 | 18:26:41 | 2.8703E-08
169 | 7/18/2019 | 18:26:42 | 2.9E-08
170 | 7/18/2019 | 18:26:43 | 3.0052E-08
171 | 7/18/2019 | 18:26:44 | 3.0401E-08
172 | 7/18/2019 | 18:26:45 | 3.1242E-08
173 | 7/18/2019 | 18:26:46 | 3.135E-08
174 | 7/18/2019 | 18:26:47 | 3.2132E-08
175 | 7/18/2019 | 18:26:48 | 3.2199E-08
176 | 7/18/2019 | 18:26:49 | 3.3227E-08
177 | 7/18/2019 | 18:26:50 | 3.3415E-08
178 | 7/18/2019 | 18:26:51 | 3.4273E-08
179 | 7/18/2019 | 18:26:52 | 3.4695E-08
180 | 7/18/2019 | 18:26:53 | 3.5246E-08
181 | 7/18/2019 | 18:26:54 | 3.5938E-08
182 | 7/18/2019 | 18:26:55 | 3.6355E-08
183 | 7/18/2019 | 18:26:56 | 3.7152E-08
184 | 7/18/2019 | 18:26:57 | 3.7437E-08
185 | 7/18/2019 | 18:26:58 | 3.829E-08
186 | 7/18/2019 | 18:26:59 | 3.8802E-08
187 | 7/18/2019 | 18:27:00 | 3.9579E-08
188 | 7/18/2019 | 18:27:01 | 4.0233E-08
189 | 7/18/2019 | 18:27:02 | 4.0787E-08
190 | 7/18/2019 | 18:27:03 | 4.1159E-08
191 | 7/18/2019 | 18:27:04 | 4.197E-08
192 | 7/18/2019 | 18:27:05 | 4.2883E-08
193 | 7/18/2019 | 18:27:06 | 4.3811E-08
194 | 7/18/2019 | 18:27:07 | 4.4694E-08
195 | 7/18/2019 | 18:27:08 | 4.5505E-08
196 | 7/18/2019 | 18:27:09 | 4.6268E-08
197 | 7/18/2019 | 18:27:10 | 4.7054E-08
198 | 7/18/2019 | 18:27:11 | 4.7528E-08
199 | 7/18/2019 | 18:27:12 | 4.8502E-08
200 | 7/18/2019 | 18:27:13 | 4.8692E-08
201 | 7/18/2019 | 18:27:14 | 4.9827E-08
202 | 7/18/2019 | 18:27:15 | 5.0176E-08
203 | 7/18/2019 | 18:27:16 | 5.1177E-08
204 | 7/18/2019 | 18:27:17 | 5.1677E-08
205 | 7/18/2019 | 18:27:18 | 5.2645E-08
206 | 7/18/2019 | 18:27:19 | 5.3175E-08
207 | 7/18/2019 | 18:27:20 | 5.3632E-08
208 | 7/18/2019 | 18:27:21 | 5.4222E-08
209 | 7/18/2019 | 18:27:22 | 5.4892E-08
210 | 7/18/2019 | 18:27:23 | 5.5403E-08
211 | 7/18/2019 | 18:27:24 | 5.5905E-08
212 | 7/18/2019 | 18:27:25 | 5.657E-08
213 | 7/18/2019 | 18:27:26 | 5.6553E-08
214 | 7/18/2019 | 18:27:27 | 5.7365E-08
215 | 7/18/2019 | 18:27:28 | 5.7301E-08
216 | 7/18/2019 | 18:27:29 | 5.7841E-08
217 | 7/18/2019 | 18:27:30 | 5.8499E-08
218 | 7/18/2019 | 18:27:31 | 5.8721E-08
219 | 7/18/2019 | 18:27:32 | 6.0059E-08
220 | 7/18/2019 | 18:27:33 | 5.9753E-08
221 | 7/18/2019 | 18:27:34 | 6.1175E-08
222 | 7/18/2019 | 18:27:35 | 6.0806E-08
223 | 7/18/2019 | 18:27:36 | 6.2289E-08
224 | 7/18/2019 | 18:27:37 | 6.185E-08
225 | 7/18/2019 | 18:27:38 | 6.3234E-08
226 | 7/18/2019 | 18:27:39 | 6.3034E-08
227 | 7/18/2019 | 18:27:40 | 6.4326E-08
228 | 7/18/2019 | 18:27:41 | 6.4283E-08
229 | 7/18/2019 | 18:27:42 | 6.5486E-08
230 | 7/18/2019 | 18:27:43 | 6.5361E-08
231 | 7/18/2019 | 18:27:44 | 6.6755E-08
232 | 7/18/2019 | 18:27:45 | 6.7125E-08
233 | 7/18/2019 | 18:27:46 | 6.8129E-08
234 | 7/18/2019 | 18:27:47 | 6.8542E-08
235 | 7/18/2019 | 18:27:48 | 6.922E-08
236 | 7/18/2019 | 18:27:49 | 6.9402E-08
237 | 7/18/2019 | 18:27:50 | 7.0289E-08
238 | 7/18/2019 | 18:27:51 | 7.0679E-08
239 | 7/18/2019 | 18:27:52 | 7.1151E-08
240 | 7/18/2019 | 18:27:53 | 7.144E-08
241 | 7/18/2019 | 18:27:54 | 7.1877E-08
242 | 7/18/2019 | 18:27:55 | 7.2598E-08
243 | 7/18/2019 | 18:27:56 | 7.2794E-08
244 | 7/18/2019 | 18:27:57 | 7.3414E-08
245 | 7/18/2019 | 18:27:58 | 7.3575E-08
246 | 7/18/2019 | 18:27:59 | 7.4381E-08
247 | 7/18/2019 | 18:28:00 | 7.4332E-08
248 | 7/18/2019 | 18:28:01 | 7.5282E-08
249 | 7/18/2019 | 18:28:02 | 7.4844E-08
250 | 7/18/2019 | 18:28:03 | 7.5946E-08
251 | 7/18/2019 | 18:28:04 | 7.5523E-08
252 | 7/18/2019 | 18:28:05 | 7.6242E-08
253 | 7/18/2019 | 18:28:06 | 7.6308E-08
254 | 7/18/2019 | 18:28:07 | 7.6969E-08
255 | 7/18/2019 | 18:28:08 | 7.7225E-08
256 | 7/18/2019 | 18:28:09 | 7.754E-08
257 | 7/18/2019 | 18:28:10 | 7.7812E-08
258 | 7/18/2019 | 18:28:11 | 7.7644E-08
259 | 7/18/2019 | 18:28:12 | 7.8193E-08
260 | 7/18/2019 | 18:28:13 | 7.8076E-08
261 | 7/18/2019 | 18:28:14 | 7.8908E-08
262 | 7/18/2019 | 18:28:15 | 7.8931E-08
263 | 7/18/2019 | 18:28:16 | 7.9381E-08
264 | 7/18/2019 | 18:28:17 | 7.9111E-08
265 | 7/18/2019 | 18:28:18 | 7.7648E-08
266 | 7/18/2019 | 18:28:19 | 7.2095E-08
267 | 7/18/2019 | 18:28:20 | 6.7182E-08
268 | 7/18/2019 | 18:28:21 | 6.1393E-08
269 | 7/18/2019 | 18:28:22 | 5.65E-08
270 | 7/18/2019 | 18:28:23 | 5.0443E-08
271 | 7/18/2019 | 18:28:24 | 4.5164E-08
272 | 7/18/2019 | 18:28:25 | 3.9539E-08
273 | 7/18/2019 | 18:28:26 | 3.4307E-08
274 | 7/18/2019 | 18:28:27 | 2.9151E-08
275 | 7/18/2019 | 18:28:28 | 2.3525E-08
276 | 7/18/2019 | 18:28:29 | 1.8604E-08
277 | 7/18/2019 | 18:28:30 | 1.2926E-08
278 | 7/18/2019 | 18:28:31 | 8.6144E-09
279 | 7/18/2019 | 18:28:32 | 3.2651E-09
280 | 7/18/2019 | 18:28:33 | -4.6267E-10
281 | 7/18/2019 | 18:28:34 | -1.2392E-09
282 | 7/18/2019 | 18:28:35 | -1.208E-09
283 | 7/18/2019 | 18:28:36 | -1.1833E-09
284 | 7/18/2019 | 18:28:37 | -1.1543E-09
285 | 7/18/2019 | 18:28:38 | -1.1244E-09
286 | 7/18/2019 | 18:28:39 | -1.0934E-09
287 | 7/18/2019 | 18:28:40 | -1.0628E-09
288 | 7/18/2019 | 18:28:41 | -1.0281E-09
289 | 7/18/2019 | 18:28:42 | -9.8721E-10
290 | 7/18/2019 | 18:28:43 | -9.5255E-10
291 | 7/18/2019 | 18:28:44 | -9.051E-10
292 | 7/18/2019 | 18:28:45 | -8.6872E-10
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

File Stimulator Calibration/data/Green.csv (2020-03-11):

Optical Power Monitor
1.1.2315.102
Delimiter Used:
Start of Measurement | 7/18/2019 17:58:46
Sample Interval | 1 s
 | PM100D 18112641
Type | PM100D
Serialnumber | P0009872
Sensor | S130VC
SensorSerialnumber | 18112641
Wavelength / Responsivity | 482 nm
 |  |  | PM100D 18112641
Samples | Date (MM/dd/yyyy) | Time of day (hh:mm:ss) | Power (W)
0 | 7/18/2019 | 17:58:46 | -1.13E-09
1 | 7/18/2019 | 17:58:47 | -1.1304E-09
2 | 7/18/2019 | 17:58:48 | -1.13E-09
3 | 7/18/2019 | 17:58:49 | -1.131E-09
4 | 7/18/2019 | 17:58:50 | -1.1309E-09
5 | 7/18/2019 | 17:58:51 | -1.1305E-09
6 | 7/18/2019 | 17:58:52 | -1.1297E-09
7 | 7/18/2019 | 17:58:53 | -1.1292E-09
8 | 7/18/2019 | 17:58:54 | -1.1285E-09
9 | 7/18/2019 | 17:58:55 | -1.1277E-09
10 | 7/18/2019 | 17:58:56 | -1.1277E-09
11 | 7/18/2019 | 17:58:57 | -1.1277E-09
12 | 7/18/2019 | 17:58:58 | -1.1245E-09
13 | 7/18/2019 | 17:58:59 | -1.121E-09
14 | 7/18/2019 | 17:59:00 | -1.1131E-09
15 | 7/18/2019 | 17:59:01 | -1.1053E-09
16 | 7/18/2019 | 17:59:02 | -1.0929E-09
17 | 7/18/2019 | 17:59:03 | -1.0823E-09
18 | 7/18/2019 | 17:59:04 | -1.0664E-09
19 | 7/18/2019 | 17:59:05 | -1.0513E-09
20 | 7/18/2019 | 17:59:06 | -1.0304E-09
21 | 7/18/2019 | 17:59:07 | -1.0111E-09
22 | 7/18/2019 | 17:59:08 | -9.8304E-10
23 | 7/18/2019 | 17:59:09 | -9.5494E-10
24 | 7/18/2019 | 17:59:10 | -9.3093E-10
25 | 7/18/2019 | 17:59:11 | -9.0137E-10
26 | 7/18/2019 | 17:59:12 | -8.7484E-10
27 | 7/18/2019 | 17:59:13 | -8.4046E-10
28 | 7/18/2019 | 17:59:14 | -8.1273E-10
29 | 7/18/2019 | 17:59:15 | -7.683E-10
30 | 7/18/2019 | 17:59:16 | -7.3599E-10
31 | 7/18/2019 | 17:59:17 | -6.9074E-10
32 | 7/18/2019 | 17:59:18 | -6.5863E-10
33 | 7/18/2019 | 17:59:19 | -6.1447E-10
34 | 7/18/2019 | 17:59:20 | -5.8339E-10
35 | 7/18/2019 | 17:59:21 | -5.3873E-10
36 | 7/18/2019 | 17:59:22 | -5.0195E-10
37 | 7/18/2019 | 17:59:23 | -4.552E-10
38 | 7/18/2019 | 17:59:24 | -4.2047E-10
39 | 7/18/2019 | 17:59:25 | -3.9859E-10
40 | 7/18/2019 | 17:59:26 | -3.7033E-10
41 | 7/18/2019 | 17:59:27 | -3.4594E-10
42 | 7/18/2019 | 17:59:28 | -3.0034E-10
43 | 7/18/2019 | 17:59:29 | -2.7529E-10
44 | 7/18/2019 | 17:59:30 | -2.3038E-10
45 | 7/18/2019 | 17:59:31 | -1.9825E-10
46 | 7/18/2019 | 17:59:32 | -1.5097E-10
47 | 7/18/2019 | 17:59:33 | -1.0588E-10
48 | 7/18/2019 | 17:59:34 | -5.7211E-11
49 | 7/18/2019 | 17:59:35 | -1.6526E-11
50 | 7/18/2019 | 17:59:36 | 2.0517E-11
51 | 7/18/2019 | 17:59:37 | 5.7355E-11
52 | 7/18/2019 | 17:59:38 | 1.1131E-10
53 | 7/18/2019 | 17:59:39 | 1.6232E-10
54 | 7/18/2019 | 17:59:40 | 2.2856E-10
55 | 7/18/2019 | 17:59:41 | 2.9551E-10
56 | 7/18/2019 | 17:59:42 | 3.4853E-10
57 | 7/18/2019 | 17:59:43 | 4.227E-10
58 | 7/18/2019 | 17:59:44 | 4.7196E-10
59 | 7/18/2019 | 17:59:45 | 5.3823E-10
60 | 7/18/2019 | 17:59:46 | 5.8478E-10
61 | 7/18/2019 | 17:59:47 | 6.5327E-10
62 | 7/18/2019 | 17:59:48 | 7.4438E-10
63 | 7/18/2019 | 17:59:49 | 8.3484E-10
64 | 7/18/2019 | 17:59:50 | 9.3633E-10
65 | 7/18/2019 | 17:59:51 | 1.0243E-09
66 | 7/18/2019 | 17:59:52 | 1.1109E-09
67 | 7/18/2019 | 17:59:53 | 1.1739E-09
68 | 7/18/2019 | 17:59:54 | 1.2729E-09
69 | 7/18/2019 | 17:59:55 | 1.3371E-09
70 | 7/18/2019 | 17:59:56 | 1.4638E-09
71 | 7/18/2019 | 17:59:57 | 1.5172E-09
72 | 7/18/2019 | 17:59:58 | 1.6589E-09
73 | 7/18/2019 | 17:59:59 | 1.701E-09
74 | 7/18/2019 | 18:00:00 | 1.8215E-09
75 | 7/18/2019 | 18:00:01 | 1.8696E-09
76 | 7/18/2019 | 18:00:02 | 1.9141E-09
77 | 7/18/2019 | 18:00:03 | 2.0498E-09
78 | 7/18/2019 | 18:00:04 | 2.0977E-09
79 | 7/18/2019 | 18:00:05 | 2.2274E-09
80 | 7/18/2019 | 18:00:06 | 2.3322E-09
81 | 7/18/2019 | 18:00:07 | 2.4617E-09
82 | 7/18/2019 | 18:00:08 | 2.5989E-09
83 | 7/18/2019 | 18:00:09 | 2.6873E-09
84 | 7/18/2019 | 18:00:10 | 2.8188E-09
85 | 7/18/2019 | 18:00:11 | 2.9048E-09
86 | 7/18/2019 | 18:00:12 | 3.0751E-09
87 | 7/18/2019 | 18:00:13 | 3.1514E-09
88 | 7/18/2019 | 18:00:14 | 3.3114E-09
89 | 7/18/2019 | 18:00:15 | 3.4338E-09
90 | 7/18/2019 | 18:00:16 | 3.5995E-09
91 | 7/18/2019 | 18:00:17 | 3.7711E-09
92 | 7/18/2019 | 18:00:18 | 3.9343E-09
93 | 7/18/2019 | 18:00:19 | 4.081E-09
94 | 7/18/2019 | 18:00:20 | 4.2594E-09
95 | 7/18/2019 | 18:00:21 | 4.4025E-09
96 | 7/18/2019 | 18:00:22 | 4.5988E-09
97 | 7/18/2019 | 18:00:23 | 4.7308E-09
98 | 7/18/2019 | 18:00:24 | 4.9394E-09
99 | 7/18/2019 | 18:00:25 | 5.0935E-09
100 | 7/18/2019 | 18:00:26 | 5.3363E-09
101 | 7/18/2019 | 18:00:27 | 5.4383E-09
102 | 7/18/2019 | 18:00:28 | 5.7283E-09
103 | 7/18/2019 | 18:00:29 | 5.8463E-09
104 | 7/18/2019 | 18:00:30 | 6.1092E-09
105 | 7/18/2019 | 18:00:31 | 6.2134E-09
106 | 7/18/2019 | 18:00:32 | 6.5348E-09
107 | 7/18/2019 | 18:00:33 | 6.6691E-09
108 | 7/18/2019 | 18:00:34 | 6.9663E-09
109 | 7/18/2019 | 18:00:35 | 7.1093E-09
110 | 7/18/2019 | 18:00:36 | 7.2654E-09
111 | 7/18/2019 | 18:00:37 | 7.5102E-09
112 | 7/18/2019 | 18:00:38 | 7.6538E-09
113 | 7/18/2019 | 18:00:39 | 7.9263E-09
114 | 7/18/2019 | 18:00:40 | 8.1943E-09
115 | 7/18/2019 | 18:00:41 | 8.4521E-09
116 | 7/18/2019 | 18:00:42 | 8.7268E-09
117 | 7/18/2019 | 18:00:43 | 9.0004E-09
118 | 7/18/2019 | 18:00:44 | 9.357E-09
119 | 7/18/2019 | 18:00:45 | 9.5001E-09
120 | 7/18/2019 | 18:00:46 | 9.8673E-09
121 | 7/18/2019 | 18:00:47 | 9.9829E-09
122 | 7/18/2019 | 18:00:48 | 1.0436E-08
123 | 7/18/2019 | 18:00:49 | 1.0582E-08
124 | 7/18/2019 | 18:00:50 | 1.0988E-08
125 | 7/18/2019 | 18:00:51 | 1.1261E-08
126 | 7/18/2019 | 18:00:52 | 1.1573E-08
127 | 7/18/2019 | 18:00:53 | 1.1757E-08
128 | 7/18/2019 | 18:00:54 | 1.2107E-08
129 | 7/18/2019 | 18:00:55 | 1.2417E-08
130 | 7/18/2019 | 18:00:56 | 1.2649E-08
131 | 7/18/2019 | 18:00:57 | 1.302E-08
132 | 7/18/2019 | 18:00:58 | 1.3361E-08
133 | 7/18/2019 | 18:00:59 | 1.3634E-08
134 | 7/18/2019 | 18:01:00 | 1.4107E-08
135 | 7/18/2019 | 18:01:01 | 1.4336E-08
136 | 7/18/2019 | 18:01:02 | 1.4786E-08
137 | 7/18/2019 | 18:01:03 | 1.5086E-08
138 | 7/18/2019 | 18:01:04 | 1.5557E-08
139 | 7/18/2019 | 18:01:05 | 1.5858E-08
140 | 7/18/2019 | 18:01:06 | 1.6286E-08
141 | 7/18/2019 | 18:01:07 | 1.6547E-08
142 | 7/18/2019 | 18:01:08 | 1.6984E-08
143 | 7/18/2019 | 18:01:09 | 1.7525E-08
144 | 7/18/2019 | 18:01:10 | 1.777E-08
145 | 7/18/2019 | 18:01:11 | 1.8259E-08
146 | 7/18/2019 | 18:01:12 | 1.8483E-08
147 | 7/18/2019 | 18:01:13 | 1.9068E-08
148 | 7/18/2019 | 18:01:14 | 1.9298E-08
149 | 7/18/2019 | 18:01:15 | 1.975E-08
150 | 7/18/2019 | 18:01:16 | 2.0015E-08
151 | 7/18/2019 | 18:01:17 | 2.027E-08
152 | 7/18/2019 | 18:01:18 | 2.0879E-08
153 | 7/18/2019 | 18:01:19 | 2.1116E-08
154 | 7/18/2019 | 18:01:20 | 2.1959E-08
155 | 7/18/2019 | 18:01:21 | 2.2194E-08
156 | 7/18/2019 | 18:01:22 | 2.2991E-08
157 | 7/18/2019 | 18:01:23 | 2.2994E-08
158 | 7/18/2019 | 18:01:24 | 2.3831E-08
159 | 7/18/2019 | 18:01:25 | 2.4171E-08
160 | 7/18/2019 | 18:01:26 | 2.501E-08
161 | 7/18/2019 | 18:01:27 | 2.5235E-08
162 | 7/18/2019 | 18:01:28 | 2.599E-08
163 | 7/18/2019 | 18:01:29 | 2.6428E-08
164 | 7/18/2019 | 18:01:30 | 2.7056E-08
165 | 7/18/2019 | 18:01:31 | 2.7593E-08
166 | 7/18/2019 | 18:01:32 | 2.8116E-08
167 | 7/18/2019 | 18:01:33 | 2.8662E-08
168 | 7/18/2019 | 18:01:34 | 2.9142E-08
169 | 7/18/2019 | 18:01:35 | 2.9947E-08
170 | 7/18/2019 | 18:01:36 | 3.0316E-08
171 | 7/18/2019 | 18:01:37 | 3.1245E-08
172 | 7/18/2019 | 18:01:38 | 3.1408E-08
173 | 7/18/2019 | 18:01:39 | 3.2465E-08
174 | 7/18/2019 | 18:01:40 | 3.266E-08
175 | 7/18/2019 | 18:01:41 | 3.3717E-08
176 | 7/18/2019 | 18:01:42 | 3.3844E-08
177 | 7/18/2019 | 18:01:43 | 3.5054E-08
178 | 7/18/2019 | 18:01:44 | 3.5183E-08
179 | 7/18/2019 | 18:01:45 | 3.6393E-08
180 | 7/18/2019 | 18:01:46 | 3.6579E-08
181 | 7/18/2019 | 18:01:47 | 3.7766E-08
182 | 7/18/2019 | 18:01:48 | 3.7891E-08
183 | 7/18/2019 | 18:01:49 | 3.8955E-08
184 | 7/18/2019 | 18:01:50 | 3.9176E-08
185 | 7/18/2019 | 18:01:51 | 3.9282E-08
186 | 7/18/2019 | 18:01:52 | 4.0508E-08
187 | 7/18/2019 | 18:01:53 | 4.0719E-08
188 | 7/18/2019 | 18:01:54 | 4.1938E-08
189 | 7/18/2019 | 18:01:55 | 4.2174E-08
190 | 7/18/2019 | 18:01:56 | 4.3357E-08
191 | 7/18/2019 | 18:01:57 | 4.3681E-08
192 | 7/18/2019 | 18:01:58 | 4.4643E-08
193 | 7/18/2019 | 18:01:59 | 4.4963E-08
194 | 7/18/2019 | 18:02:00 | 4.5942E-08
195 | 7/18/2019 | 18:02:01 | 4.6418E-08
196 | 7/18/2019 | 18:02:02 | 4.7309E-08
197 | 7/18/2019 | 18:02:03 | 4.799E-08
198 | 7/18/2019 | 18:02:04 | 4.8782E-08
199 | 7/18/2019 | 18:02:05 | 4.9476E-08
200 | 7/18/2019 | 18:02:06 | 4.9883E-08
201 | 7/18/2019 | 18:02:07 | 5.0764E-08
202 | 7/18/2019 | 18:02:08 | 5.0871E-08
203 | 7/18/2019 | 18:02:09 | 5.1889E-08
204 | 7/18/2019 | 18:02:10 | 5.1918E-08
205 | 7/18/2019 | 18:02:11 | 5.3004E-08
206 | 7/18/2019 | 18:02:12 | 5.3128E-08
207 | 7/18/2019 | 18:02:13 | 5.4368E-08
208 | 7/18/2019 | 18:02:14 | 5.4484E-08
209 | 7/18/2019 | 18:02:15 | 5.5547E-08
210 | 7/18/2019 | 18:02:16 | 5.5652E-08
211 | 7/18/2019 | 18:02:17 | 5.6543E-08
212 | 7/18/2019 | 18:02:18 | 5.6835E-08
213 | 7/18/2019 | 18:02:19 | 5.783E-08
214 | 7/18/2019 | 18:02:20 | 5.8305E-08
215 | 7/18/2019 | 18:02:21 | 5.9261E-08
216 | 7/18/2019 | 18:02:22 | 5.9795E-08
217 | 7/18/2019 | 18:02:23 | 6.0467E-08
218 | 7/18/2019 | 18:02:24 | 6.1323E-08
219 | 7/18/2019 | 18:02:25 | 6.1425E-08
220 | 7/18/2019 | 18:02:26 | 6.2104E-08
221 | 7/18/2019 | 18:02:27 | 6.2506E-08
222 | 7/18/2019 | 18:02:28 | 6.317E-08
223 | 7/18/2019 | 18:02:29 | 6.3679E-08
224 | 7/18/2019 | 18:02:30 | 6.4295E-08
225 | 7/18/2019 | 18:02:31 | 6.4964E-08
226 | 7/18/2019 | 18:02:32 | 6.5523E-08
227 | 7/18/2019 | 18:02:33 | 6.611E-08
228 | 7/18/2019 | 18:02:34 | 6.6417E-08
229 | 7/18/2019 | 18:02:35 | 6.7158E-08
230 | 7/18/2019 | 18:02:36 | 6.7356E-08
231 | 7/18/2019 | 18:02:37 | 6.818E-08
232 | 7/18/2019 | 18:02:38 | 6.8135E-08
233 | 7/18/2019 | 18:02:39 | 6.8978E-08
234 | 7/18/2019 | 18:02:40 | 6.9305E-08
235 | 7/18/2019 | 18:02:41 | 7.0003E-08
236 | 7/18/2019 | 18:02:42 | 7.0163E-08
237 | 7/18/2019 | 18:02:43 | 7.0948E-08
238 | 7/18/2019 | 18:02:44 | 7.1161E-08
239 | 7/18/2019 | 18:02:45 | 7.1836E-08
240 | 7/18/2019 | 18:02:46 | 7.2075E-08
241 | 7/18/2019 | 18:02:47 | 7.2895E-08
242 | 7/18/2019 | 18:02:48 | 7.304E-08
243 | 7/18/2019 | 18:02:49 | 7.3799E-08
244 | 7/18/2019 | 18:02:50 | 7.3907E-08
245 | 7/18/2019 | 18:02:51 | 7.4732E-08
246 | 7/18/2019 | 18:02:52 | 7.4837E-08
247 | 7/18/2019 | 18:02:53 | 7.5443E-08
248 | 7/18/2019 | 18:02:54 | 7.5651E-08
249 | 7/18/2019 | 18:02:55 | 7.6266E-08
250 | 7/18/2019 | 18:02:56 | 7.6502E-08
251 | 7/18/2019 | 18:02:57 | 7.7061E-08
252 | 7/18/2019 | 18:02:58 | 7.7382E-08
253 | 7/18/2019 | 18:02:59 | 7.7754E-08
254 | 7/18/2019 | 18:03:00 | 7.8055E-08
255 | 7/18/2019 | 18:03:01 | 7.8461E-08
256 | 7/18/2019 | 18:03:02 | 7.8832E-08
257 | 7/18/2019 | 18:03:03 | 7.9101E-08
258 | 7/18/2019 | 18:03:04 | 7.9427E-08
259 | 7/18/2019 | 18:03:05 | 7.9447E-08
260 | 7/18/2019 | 18:03:06 | 7.9761E-08
261 | 7/18/2019 | 18:03:07 | 8.0034E-08
262 | 7/18/2019 | 18:03:08 | 8.0236E-08
263 | 7/18/2019 | 18:03:09 | 8.0555E-08
264 | 7/18/2019 | 18:03:10 | 8.0599E-08
265 | 7/18/2019 | 18:03:11 | 7.9516E-08
266 | 7/18/2019 | 18:03:12 | 7.2914E-08
267 | 7/18/2019 | 18:03:13 | 6.5751E-08
268 | 7/18/2019 | 18:03:14 | 5.8016E-08
269 | 7/18/2019 | 18:03:15 | 5.0706E-08
270 | 7/18/2019 | 18:03:16 | 4.3688E-08
271 | 7/18/2019 | 18:03:17 | 3.6583E-08
272 | 7/18/2019 | 18:03:18 | 2.964E-08
273 | 7/18/2019 | 18:03:19 | 2.2486E-08
274 | 7/18/2019 | 18:03:20 | 1.5764E-08
275 | 7/18/2019 | 18:03:21 | 8.8722E-09
276 | 7/18/2019 | 18:03:22 | 2.1433E-09
277 | 7/18/2019 | 18:03:23 | -9.9189E-10
278 | 7/18/2019 | 18:03:24 | -9.7338E-10
279 | 7/18/2019 | 18:03:25 | -9.4046E-10
280 | 7/18/2019 | 18:03:26 | -9.186E-10
281 | 7/18/2019 | 18:03:27 | -8.7737E-10
282 | 7/18/2019 | 18:03:28 | -8.5516E-10
283 | 7/18/2019 | 18:03:29 | -8.191E-10
284 | 7/18/2019 | 18:03:30 | -7.9239E-10
285 | 7/18/2019 | 18:03:31 | -7.5416E-10
286 | 7/18/2019 | 18:03:32 | -7.1945E-10
287 | 7/18/2019 | 18:03:33 | -6.8272E-10
288 | 7/18/2019 | 18:03:34 | -6.4339E-10
289 | 7/18/2019 | 18:03:35 | -6.0617E-10
290 | 7/18/2019 | 18:03:36 | -5.6874E-10
291 | 7/18/2019 | 18:03:37 | -5.3799E-10
292 | 7/18/2019 | 18:03:38 | -4.8892E-10
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

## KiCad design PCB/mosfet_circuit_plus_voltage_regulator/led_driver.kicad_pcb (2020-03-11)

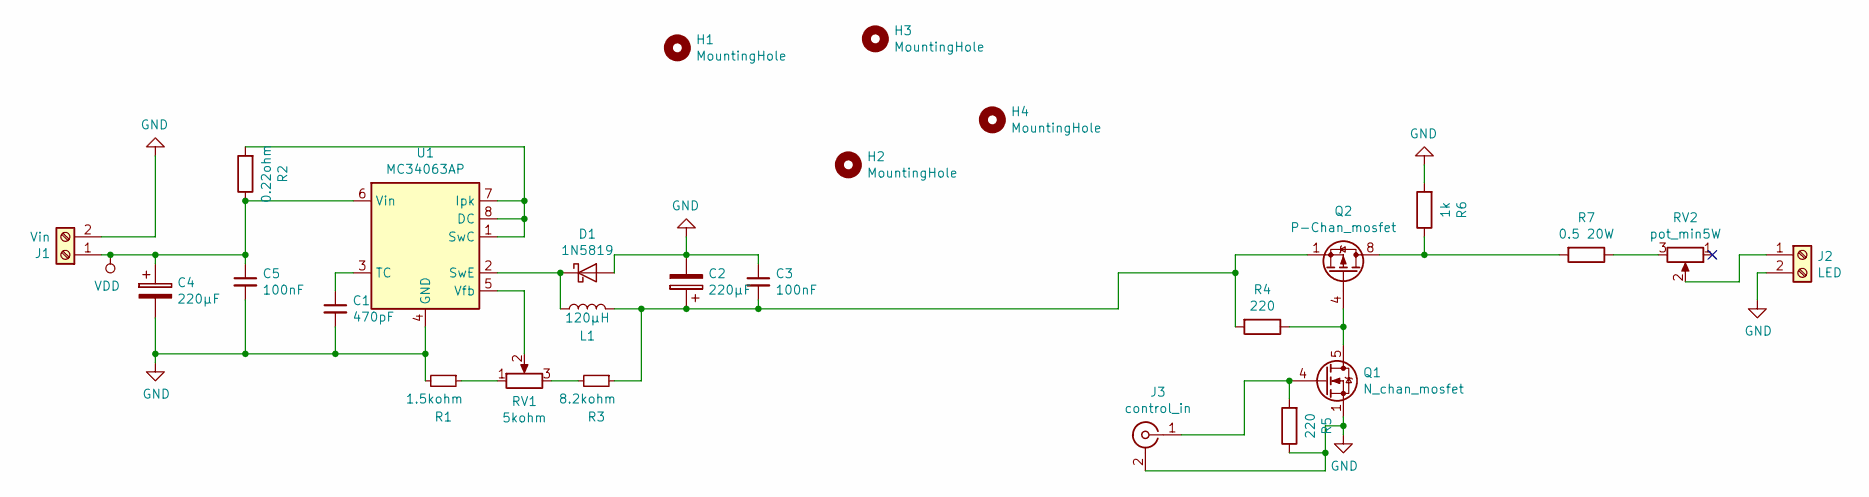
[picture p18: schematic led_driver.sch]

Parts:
C1: 470pF; CP_Radial_D5.0mm_P2.50mm
C2, C4: 220µF; CP_Radial_D8.0mm_P5.00mm
C3, C5: 100nF; C_Disc_D8.0mm_W5.0mm_P7.50mm
D1: 1N5819; D_DO-41_SOD81_P10.16mm_Horizontal
H1, H2, H3, H4: MountingHole; MountingHole_3.2mm_M3
J1: Vin; TerminalBlock_Altech_AK300-2_P5.00mm
J2: LED; TerminalBlock_Altech_AK300-2_P5.00mm
J3: control_in; BNC_Amphenol_B6252HB-NPP3G-50_Horizontal
L1: 120µH; L_Radial_D7.5mm_P5.00mm_Fastron_07P
Q1: N_chan_mosfet; TDSON-8-1
Q2: P-Chan_mosfet; SOIC-8_3.9x4.9mm_P1.27mm
R1: 1.5kohm; R_Axial_DIN0207_L6.3mm_D2.5mm_P10.16mm_Horizontal
R2: 0.22ohm; R_Axial_DIN0414_L11.9mm_D4.5mm_P15.24mm_Horizontal
R3: 8.2kohm; R_Axial_DIN0207_L6.3mm_D2.5mm_P10.16mm_Horizontal
R4, R5: 220; R_Axial_DIN0207_L6.3mm_D2.5mm_P10.16mm_Horizontal
R6: 1k; R_Axial_DIN0207_L6.3mm_D2.5mm_P10.16mm_Horizontal
R7: 0.5 20W; TO-220-2_Vertical
RV1: 5kohm; Potentiometer_Vishay_T73YP_Vertical
RV2: pot_min5W; Potentiometer_ACP_CA14-H5_Horizontal
U1: MC34063AP; DIP-8_W7.62mm

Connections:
GND: C1.2, C2.2, C3.1, C4.2, C5.2, D1.2 (A), J1.2, J2.2, J3.2 (Ext), Q1.1 (S), Q1.2 (S), Q1.3 (S), R1.2, R5.1, R6.2, U1.4 (GND)
unnamed: C1.1, U1.3 (TC)
unnamed: C2.1, C3.2, L1.2, Q2.1 (S), Q2.2 (S), Q2.3 (S), R3.1, R4.2
unnamed: D1.1 (K), L1.1, U1.2 (SwE)
unnamed: J2.1, RV2.2
unnamed: J3.1 (In), Q1.4 (G), R5.2
unnamed: Q1.5 (D), Q2.4 (G), R4.1
unnamed: Q2.5 (D), Q2.6 (D), Q2.7 (D), Q2.8 (D), R6.1, R7.2
unnamed: R1.1, RV1.1
unnamed: R2.2, U1.1 (SwC), U1.7 (Ipk), U1.8 (DC)
unnamed: R3.2, RV1.3
unnamed: R7.1, RV2.3
unnamed: RV1.2, U1.5 (Vfb)
VDD: C4.1, C5.1, J1.1, R2.1, U1.6 (Vin)

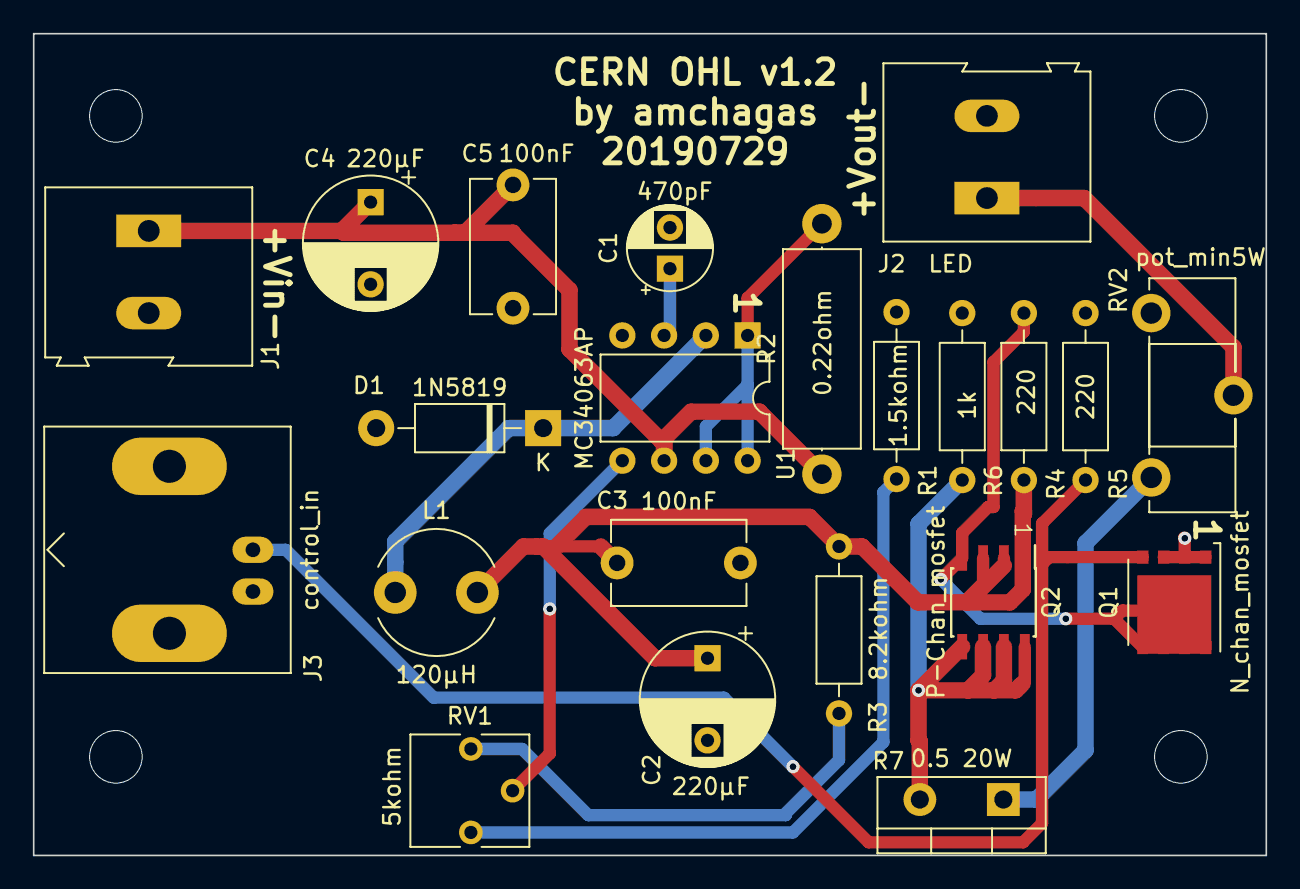
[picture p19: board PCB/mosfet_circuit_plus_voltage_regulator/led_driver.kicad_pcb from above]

Board: 2 copper layers, 75.0 x 50.0 mm, 26 parts (0 on the bottom side), 14 nets.

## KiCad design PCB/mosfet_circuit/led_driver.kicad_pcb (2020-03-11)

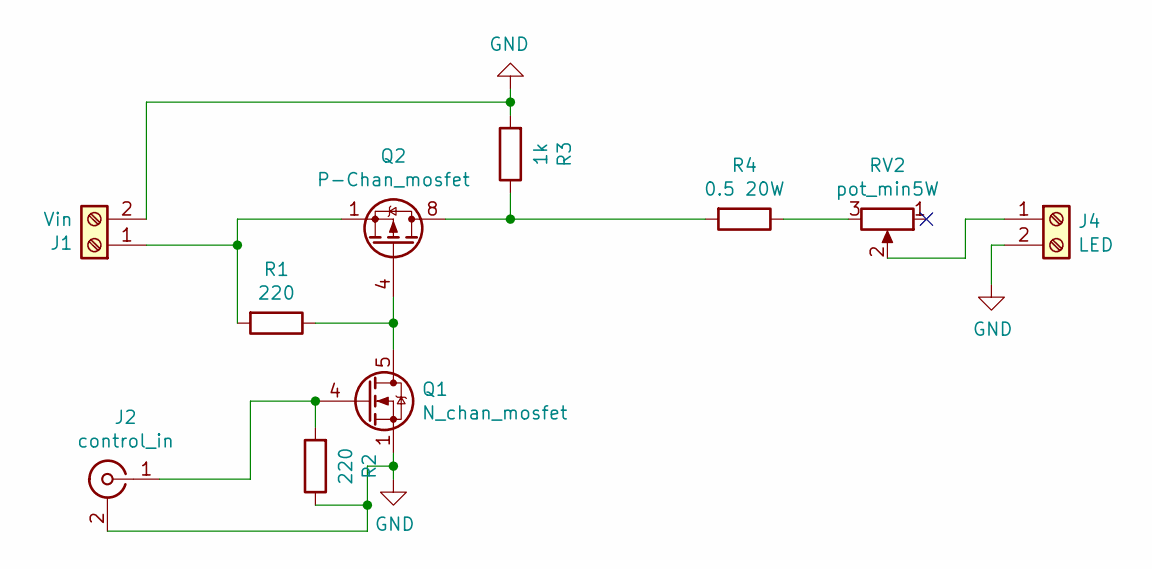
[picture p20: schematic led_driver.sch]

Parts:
J1: Vin; TerminalBlock_Altech_AK300-2_P5.00mm
J2: control_in; BNC_Amphenol_B6252HB-NPP3G-50_Horizontal
J4: LED; TerminalBlock_Altech_AK300-2_P5.00mm
Q1: N_chan_mosfet; TDSON-8-1
Q2: P-Chan_mosfet; SOIC-8_3.9x4.9mm_P1.27mm
R1, R2: 220; R_Axial_DIN0207_L6.3mm_D2.5mm_P10.16mm_Horizontal
R3: 1k; R_Axial_DIN0207_L6.3mm_D2.5mm_P10.16mm_Horizontal
R4: 0.5 20W; R_Axial_DIN0207_L6.3mm_D2.5mm_P10.16mm_Horizontal
RV2: pot_min5W; Potentiometer_ACP_CA14-H5_Horizontal

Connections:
GND: J1.2, J2.2 (Ext), J4.2, Q1.1 (S), Q1.2 (S), Q1.3 (S), R2.1, R3.2
unnamed: J1.1, Q2.1 (S), Q2.2 (S), Q2.3 (S), R1.2
unnamed: J2.1 (In), Q1.4 (G), R2.2
unnamed: J4.1, RV2.2
unnamed: Q1.5 (D), Q2.4 (G), R1.1
unnamed: Q2.5 (D), Q2.6 (D), Q2.7 (D), Q2.8 (D), R3.1, R4.2
unnamed: R4.1, RV2.3

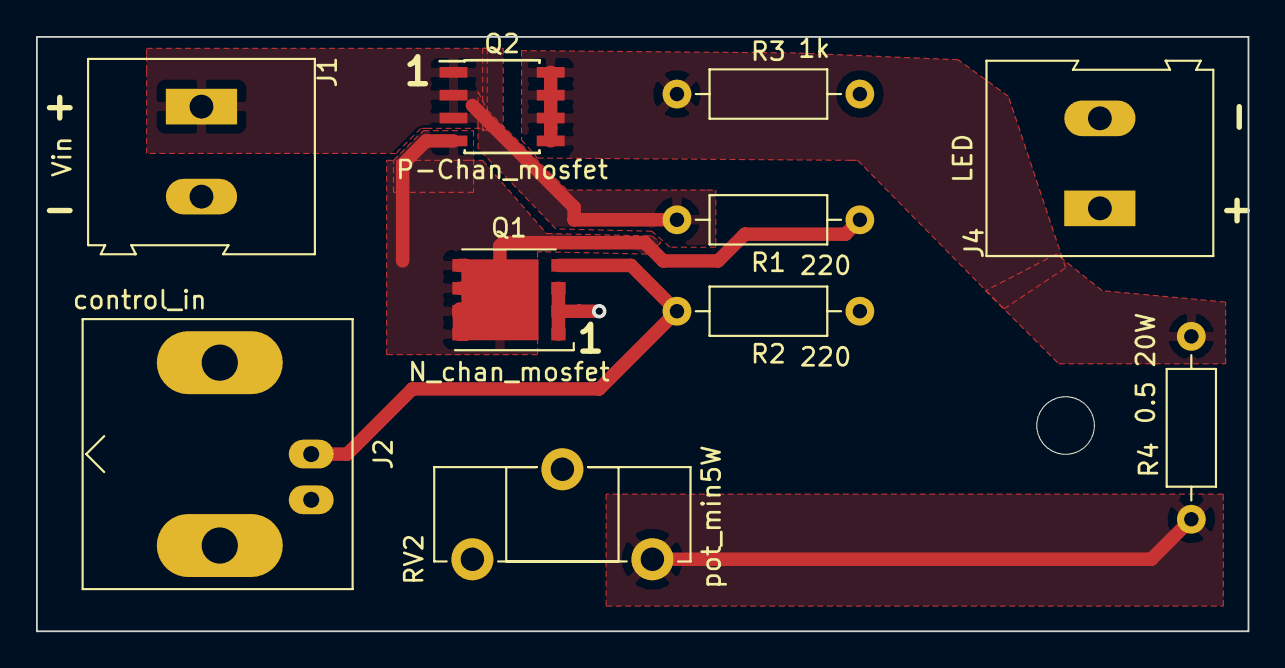
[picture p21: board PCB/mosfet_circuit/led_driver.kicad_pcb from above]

Board: 2 copper layers, 67.3 x 33.0 mm, 10 parts (0 on the bottom side), 7 nets.

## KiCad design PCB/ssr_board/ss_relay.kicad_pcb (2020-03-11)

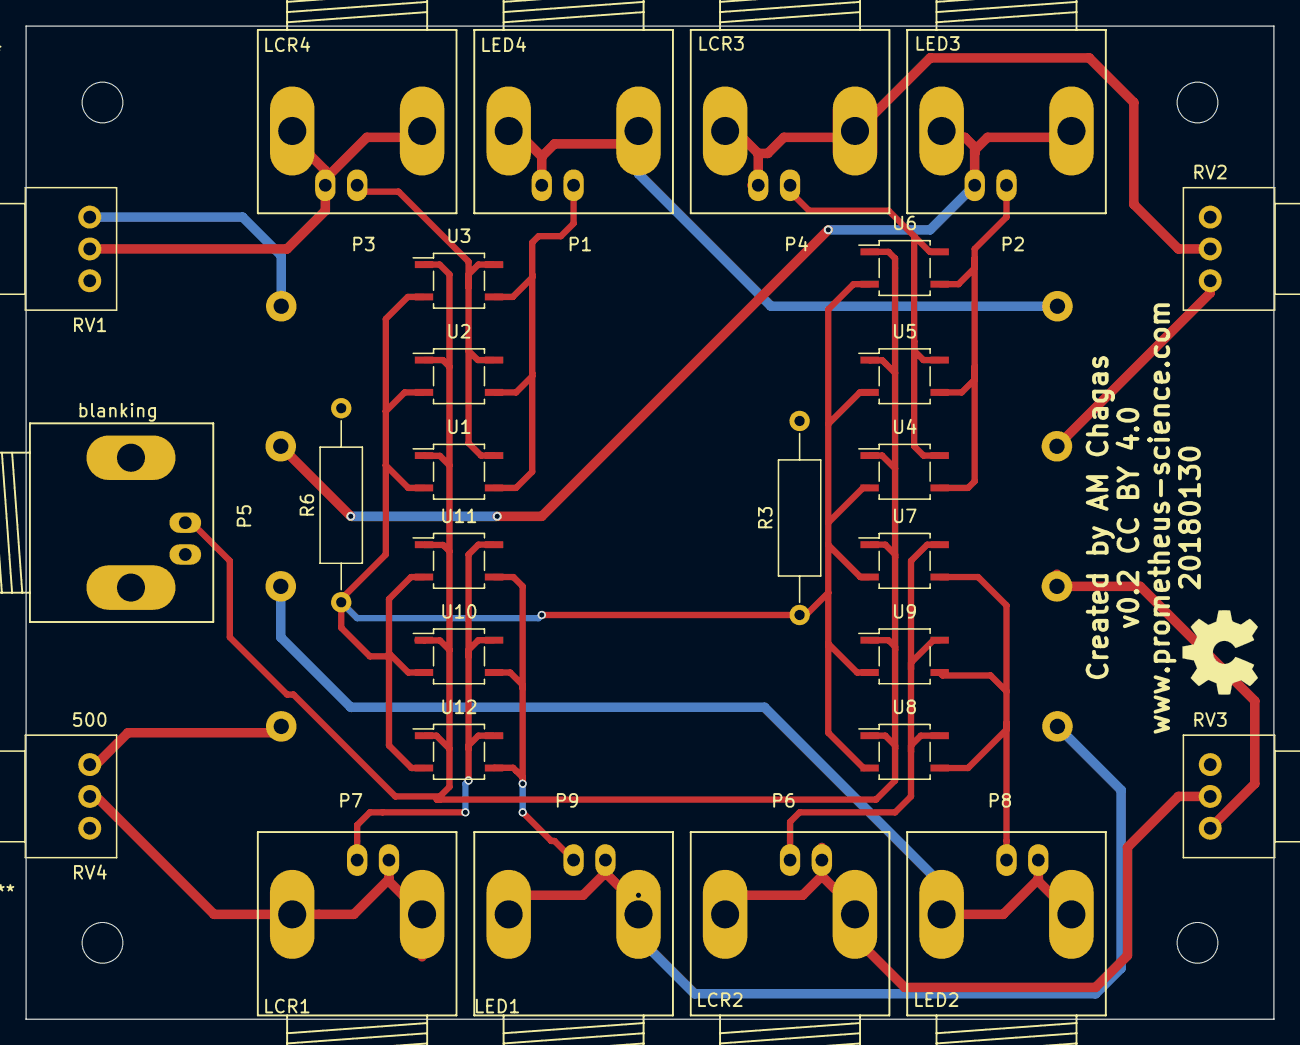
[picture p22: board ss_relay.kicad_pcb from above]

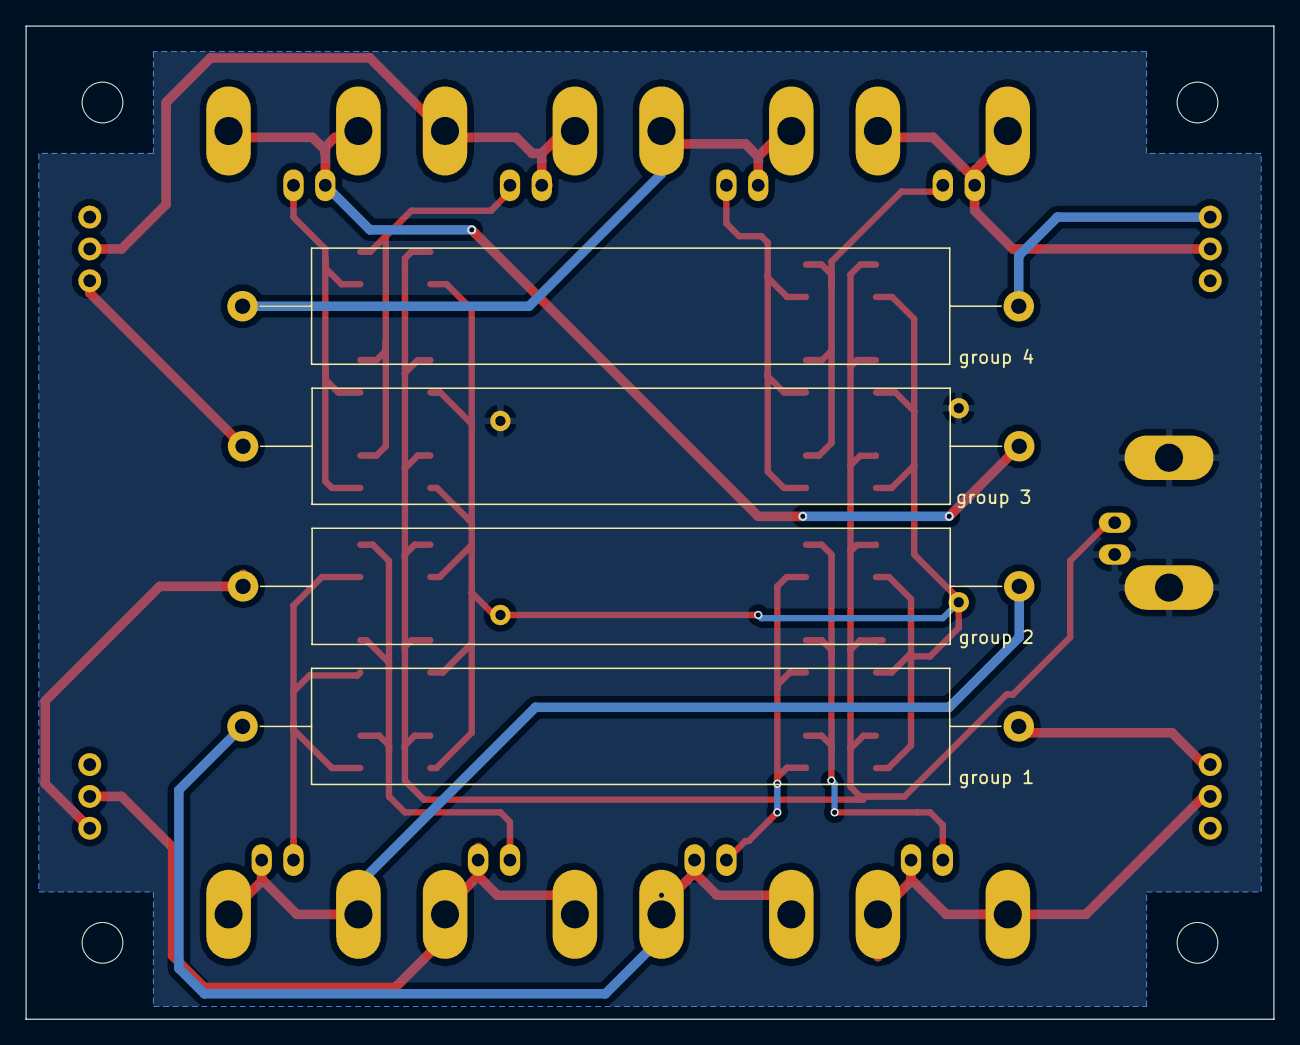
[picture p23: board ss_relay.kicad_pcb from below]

Board: 2 copper layers, 98.0 x 78.0 mm, 31 parts (4 on the bottom side), 23 nets.

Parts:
P1: LED4; BNC_Socket_TYCO-AMP_LargePads
P2: LED3; BNC_Socket_TYCO-AMP_LargePads
P3: LCR4; BNC_Socket_TYCO-AMP_LargePads
P4: LCR3; BNC_Socket_TYCO-AMP_LargePads
P5: blanking; BNC_Socket_TYCO-AMP_LargePads
P6: LCR2; BNC_Socket_TYCO-AMP_LargePads
P7: LCR1; BNC_Socket_TYCO-AMP_LargePads
P8: LED2; BNC_Socket_TYCO-AMP_LargePads
P9: LED1; BNC_Socket_TYCO-AMP_LargePads
R3, R6: 270; R_Axial_DIN0309_L9.0mm_D3.2mm_P15.24mm_Horizontal
RV1, RV2, RV3, RV4: 500; Potentiometer_Alps_RK097_Single_Vertical
U1, U2, U3, U4, U5, U6, U7, U8, U9, U10, U11, U12: TLP291; SOP-4_3.8x4.1mm_Pitch2.54mm
group 1, group 2, group 3, group 4: 10; R_Axial_Power_L50.0mm_W9.0mm_P60.96mm

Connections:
GND: P5.2, R3.2, R6.2
unnamed: P1.1, U1.3, U2.3, U3.3
unnamed: P1.2, group 4.1
unnamed: P2.1, U4.3, U5.3, U6.3
unnamed: P2.2, group 3.1
unnamed: P3.1, U1.4, U2.4, U3.4
unnamed: P3.2, RV1.2
unnamed: P4.1, U4.4, U5.4, U6.4
unnamed: P4.2, RV2.2
unnamed: P5.1, U1.1, U2.1, U3.1, U4.1, U5.1, U6.1, U7.1, U8.1, U9.1, U10.1, U11.1, U12.1
unnamed: P6.1, U7.4, U8.4, U9.4
unnamed: P6.2, RV3.2
unnamed: P7.1, U10.4, U11.4, U12.4
unnamed: P7.2, RV4.2
unnamed: P8.1, U7.3, U8.3, U9.3
unnamed: P8.2, group 2.1
unnamed: P9.1, U10.3, U11.3, U12.3
unnamed: P9.2, group 1.1
unnamed: RV1.1, group 4.2
unnamed: RV2.1, group 3.2
unnamed: R3.1, R6.1, U1.2, U2.2, U3.2, U4.2, U5.2, U6.2, U7.2, U8.2, U9.2, U10.2, U11.2, U12.2
unnamed: RV3.1, group 2.2
unnamed: RV4.1, group 1.2

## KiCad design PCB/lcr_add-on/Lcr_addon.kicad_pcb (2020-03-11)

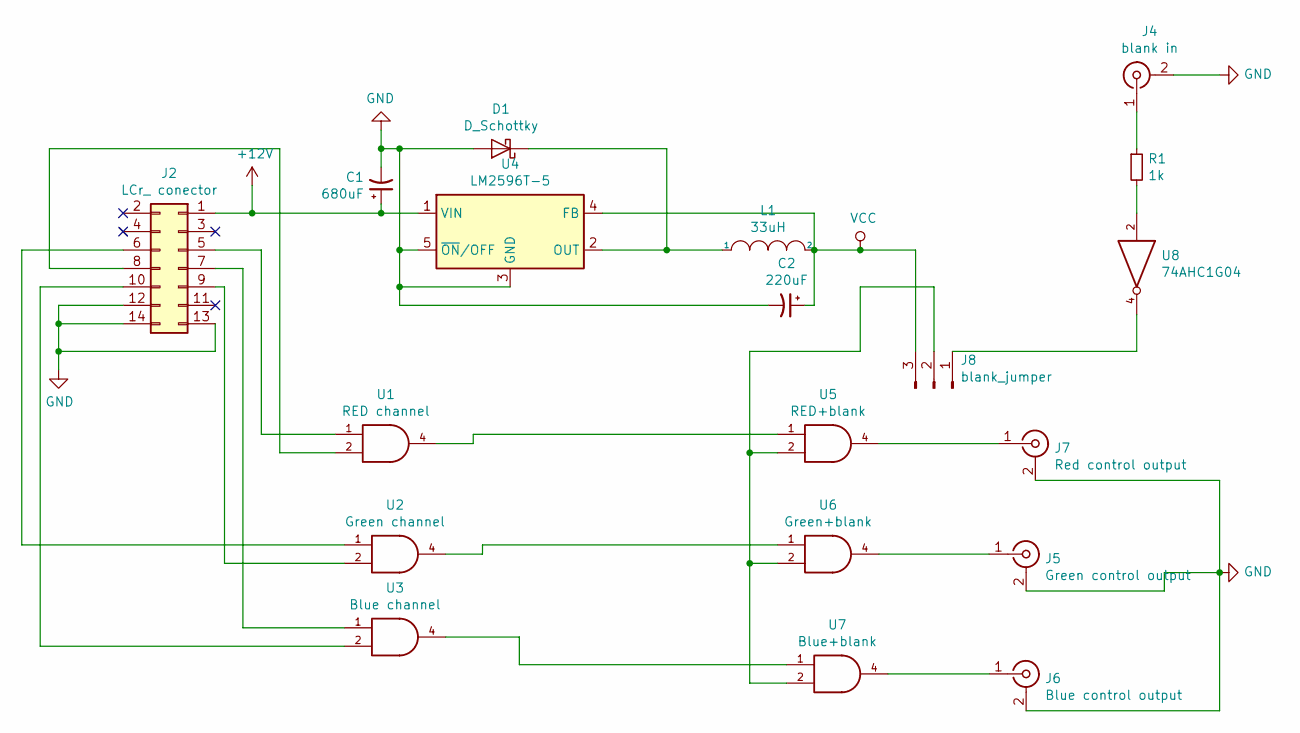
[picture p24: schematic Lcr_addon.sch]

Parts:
C1: 680uF; CP_Radial_D6.3mm_P2.50mm
C2: 220uF; CP_Radial_D6.3mm_P2.50mm
D1: D_Schottky; D_DO-201AD_P15.24mm_Horizontal
J2: LCr_ conector; JST_PUD_B14B-PUDSS_2x07_P2.00mm_Vertical
J4: blank in; BNC_Amphenol_B6252HB-NPP3G-50_Horizontal
J5: Green control output; BNC_Amphenol_B6252HB-NPP3G-50_Horizontal
J6: Blue control output; BNC_Amphenol_B6252HB-NPP3G-50_Horizontal
J7: Red control output; BNC_Amphenol_B6252HB-NPP3G-50_Horizontal
J8: blank_jumper; PinHeader_1x03_P2.54mm_Vertical
L1: 33uH; L_Radial_D10.0mm_P5.00mm_Neosid_SD12_style3
R1: 1k; R_Axial_DIN0207_L6.3mm_D2.5mm_P2.54mm_Vertical
U1: RED channel; TSOP-5_1.65x3.05mm_P0.95mm
U2: Green channel; TSOP-5_1.65x3.05mm_P0.95mm
U3: Blue channel; TSOP-5_1.65x3.05mm_P0.95mm
U4: LM2596T-5; TO-220-5_P3.4x3.7mm_StaggerOdd_Lead3.8mm_Vertical
U5: RED+blank; TSOP-5_1.65x3.05mm_P0.95mm
U6: Green+blank; TSOP-5_1.65x3.05mm_P0.95mm
U7: Blue+blank; TSOP-5_1.65x3.05mm_P0.95mm
U8: 74AHC1G04; TSOP-5_1.65x3.05mm_P0.95mm

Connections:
+12V: C1.1, J2.1, U4.1 (VIN)
GND: C1.2, C2.2, D1.2 (A), J2.12, J2.13, J2.14, J4.2 (Ext), J5.2 (Ext), J6.2 (Ext), J7.2 (Ext), U1.3 (GND), U2.3 (GND), U3.3 (GND), U4.3 (GND), U4.5 (~ON~/OFF), U5.3 (GND), U6.3 (GND), U7.3 (GND), U8.3 (GND)
unnamed: D1.1 (K), L1.1, U4.2 (OUT)
unnamed: J2.5, U1.1
unnamed: J2.6, U2.1
unnamed: J2.7, U3.1
unnamed: J2.8, U1.2
unnamed: J2.9, U2.2
unnamed: J2.10, U3.2
unnamed: J4.1 (In), R1.1
unnamed: J5.1 (In), U6.4
unnamed: J6.1 (In), U7.4
unnamed: J7.1 (In), U5.4
unnamed: J8.1, U8.4
unnamed: J8.2, U5.2, U6.2, U7.2
unnamed: R1.2, U8.2
unnamed: U1.4, U5.1
unnamed: U2.4, U6.1
unnamed: U3.4, U7.1
VCC: C2.1, J8.3, L1.2, U1.5 (VCC), U2.5 (VCC), U3.5 (VCC), U4.4 (FB), U5.5 (VCC), U6.5 (VCC), U7.5 (VCC), U8.5 (VCC)

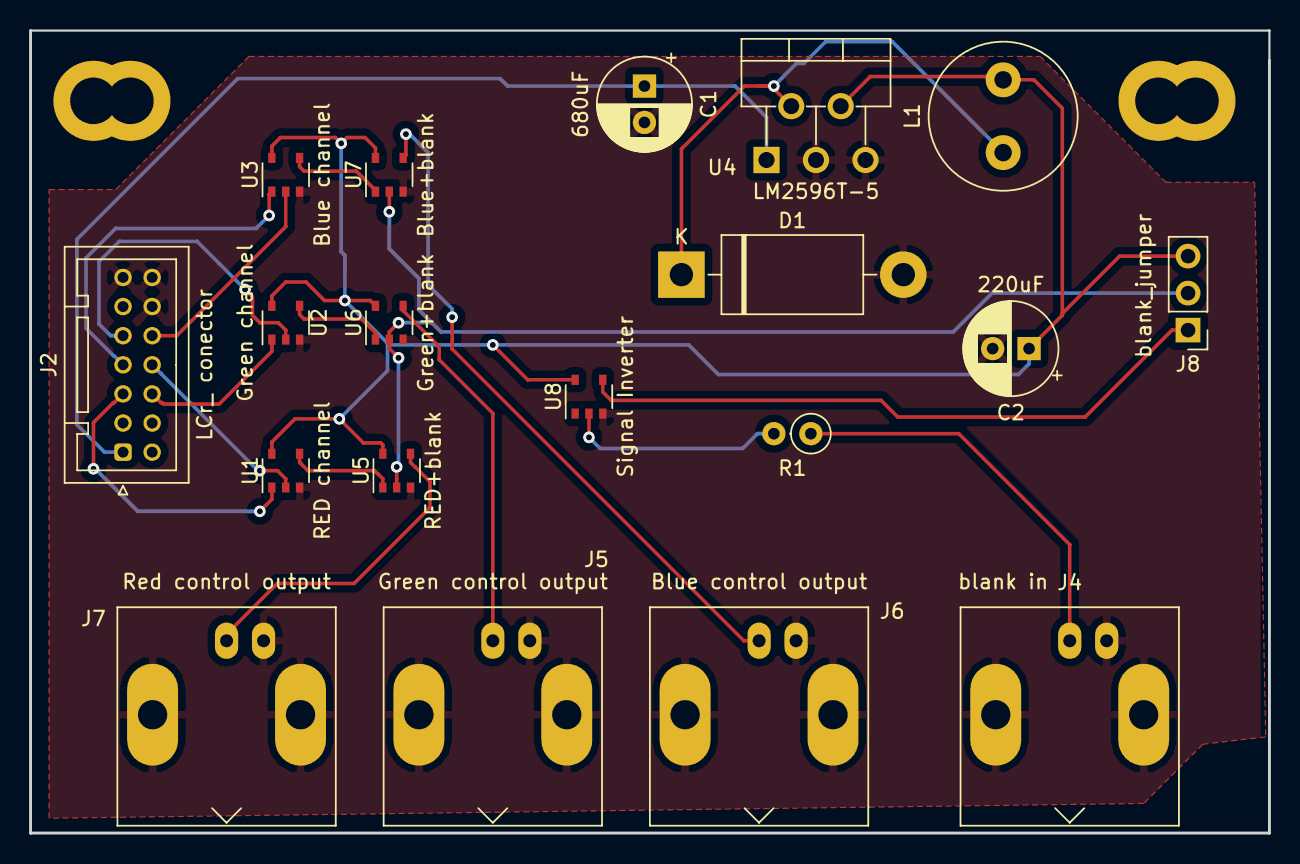
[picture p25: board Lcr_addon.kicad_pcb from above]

Board: 2 copper layers, 85.1 x 55.1 mm, 19 parts (0 on the bottom side), 20 nets.

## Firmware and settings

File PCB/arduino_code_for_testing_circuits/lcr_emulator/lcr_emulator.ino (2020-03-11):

// constants won't change. Used here to set a pin number:
const int pin12 =  12;// the number of the LED pin
const int pin11 =  11;// the number of the LED pin
const int pin10 =  10;// the number of the LED pin



// Generally, you should use "unsigned long" for variables that hold time
// The value will quickly become too large for an int to store
unsigned long millis1 = 0;        // will store last time LED was updated
unsigned long millis2 = 0;
unsigned long millis3 = 0;

unsigned long millis12 = 0;        // will store last time LED was updated
unsigned long millis11 = 0;        // will store last time LED was updated
unsigned long millis10 = 0;        // will store last time LED was updated



void setup() {
  // set the digital pin as output:
  pinMode(pin10, OUTPUT);
  pinMode(pin11, OUTPUT);
  pinMode(pin12, OUTPUT);
  millis1=micros();
  millis10=micros();
  millis2=millis();
  millis11=millis();
  millis3=millis();
  millis12=millis();
}

void loop() {
  
  millis10=micros();
  millis11=millis();
  millis12=millis();
  
  if (millis10 - millis1 <= 400) {
    // save the last time you blinked the LED
    digitalWrite(pin10,LOW);
  }
  if (millis10-millis1>400){
    digitalWrite(pin10,HIGH);
  }
    if (millis10-millis1>=2000){
      millis1=micros();
      
  }

  if (millis11-millis2<=5){
    digitalWrite(pin11,HIGH);
  }
  if (millis11-millis2>5){
    digitalWrite(pin11,LOW);
  }  
    if (millis11-millis2>=10){
    millis2=millis();
   
  }  

  if (millis12-millis3<=50){
    digitalWrite(pin12,HIGH);
  }
  if (millis12-millis3>50){
    digitalWrite(pin12,LOW);
  }  
    if (millis12-millis3>=100){
    millis3=millis();
   
  }  
}
    

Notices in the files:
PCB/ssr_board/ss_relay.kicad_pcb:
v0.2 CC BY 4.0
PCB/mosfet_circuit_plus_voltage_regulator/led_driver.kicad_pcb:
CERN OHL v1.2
